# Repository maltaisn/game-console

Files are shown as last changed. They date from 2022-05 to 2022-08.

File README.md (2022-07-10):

# Handheld game console

A small six-button handheld game console with a bootloader and games stored in external flash memory.
A complete solution was created to create, simulate, compile and upload apps for the device.

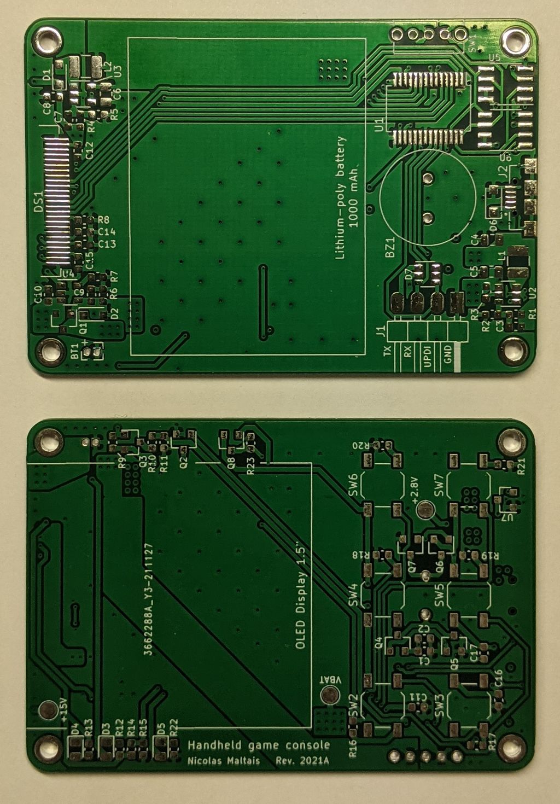
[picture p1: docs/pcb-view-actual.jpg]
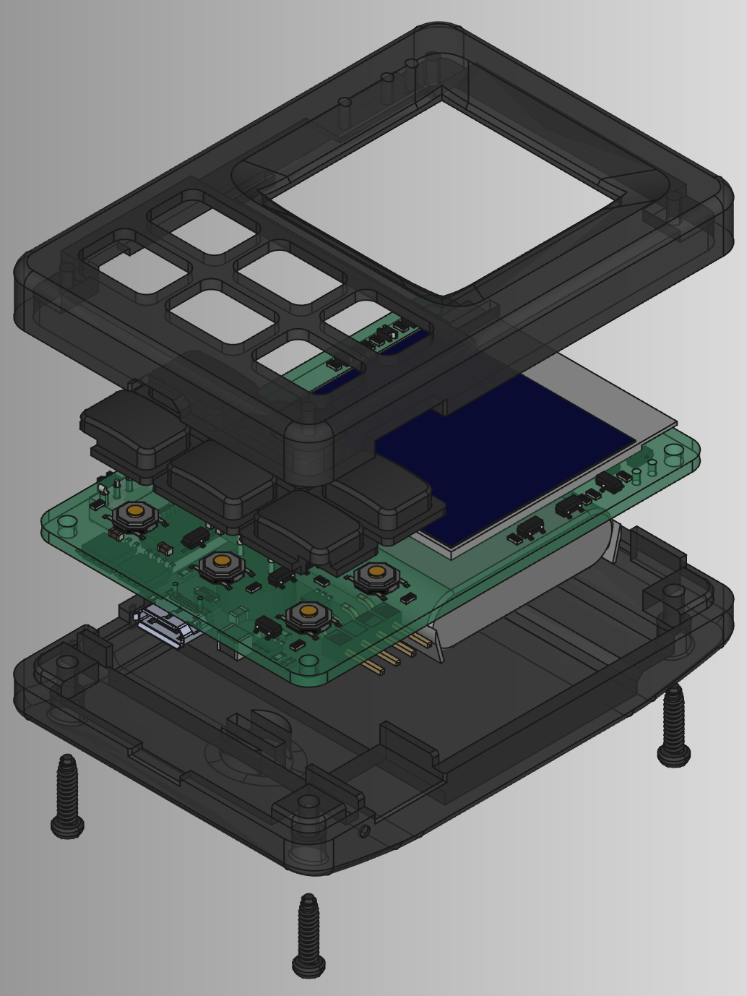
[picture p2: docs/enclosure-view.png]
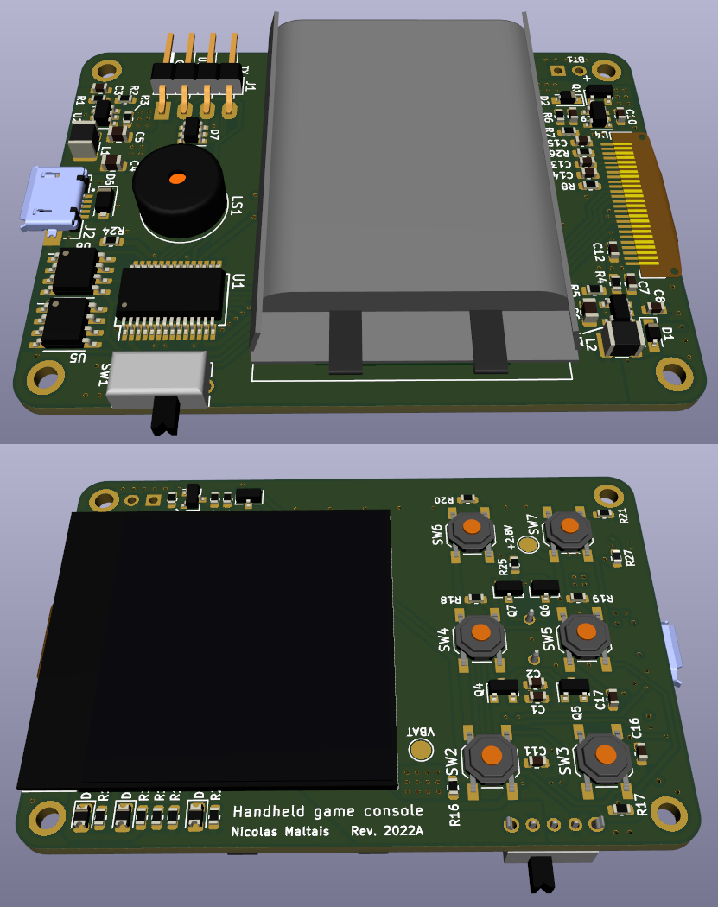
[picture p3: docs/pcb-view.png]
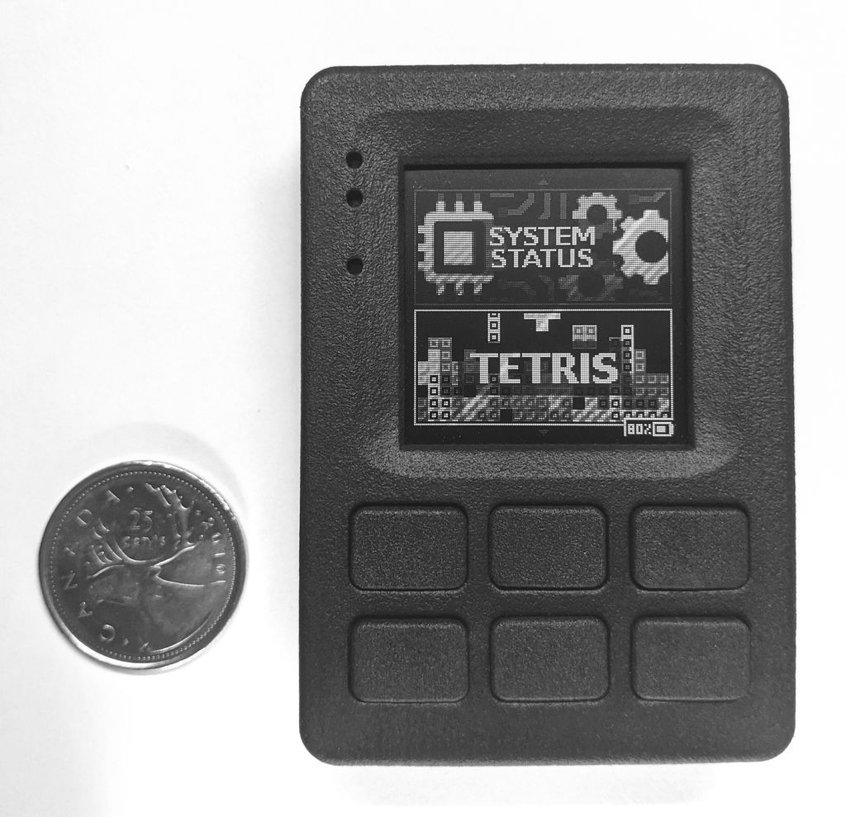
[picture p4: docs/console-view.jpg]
   

There are currently 2 games written for the console:

- [Tetris](sw/app/tetris)
- [Tile World](sw/app/tworld)

## Specifications

- Display: 1.5" OLED 128x128, 4-bit gray.
- MCU: ATmega3208 @ 10 MHz, 4 kB RAM, 32 kB ROM (bootloader uses 8.25 kB).
- Memory: 4 kB EEPROM (up to 64 kB), 1 MB flash (up to 8 MB).
- Physical: 40 mm x 71 mm x 15.4 mm, 60 g.
- Battery: 850 mAh Li-Po, 5-20h active, several months standby, USB micro B charging.

### Hardware

- MCU: ATmega3208, compatible with ATmega4808, AVR128DA28, AVR64DA28, AVR32DA28 (none tested).
- EEPROM: FT25C32A, 4 kB (compatible with same series devices)
- Flash: AT25SF081B, 1 MB (compatible with 25-series flash devices)
- Display: EastRising ER-OLED015-3 (SSD1327 display controller, 15V VCC)

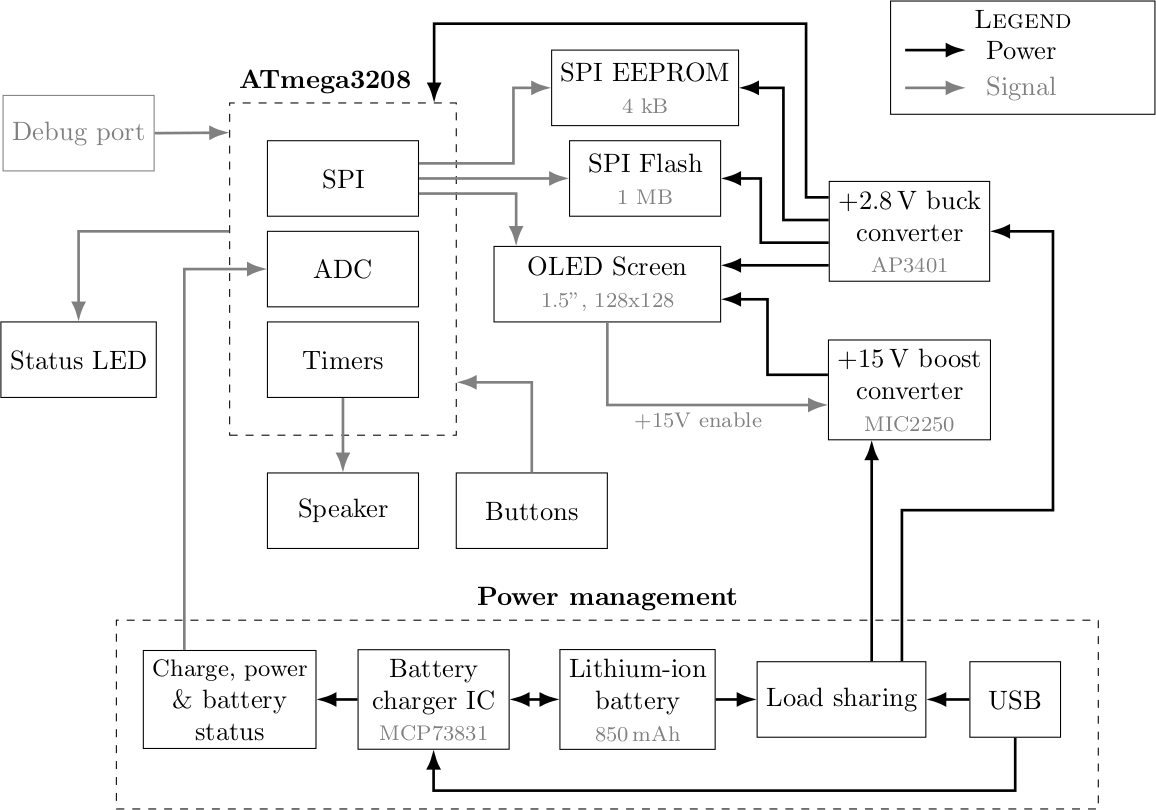
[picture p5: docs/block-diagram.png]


## Tools and building

Everything was built and tested on Linux only (Ubuntu 20.04).
The PCB was made in KiCAD 6 and the enclosure was made in FreeCAD 0.19.
Building and using the software requires the following tools and libraries:

- AVR GCC >= 5.4.0 (7.3.0 used)
- GCC >= 9
- Python >= 3.7
- freeglut, pulseaudio, libpng

## Architecture

The architecture of the software is described in details in [`sw/README.md`](sw/README.md).

## Project structure

- `hw`: PCB and enclosure
- `sw`: all software SDK including programming utility and all apps.
- `docs`: documentation source files

## License

All code is licensed under Apache License 2.0 and all assets are licensed under
Creative Commons v4.0, unless otherwise indicated.
Bitmap fonts were taken from the [u8g2](https://github.com/olikraus/u8g2/wiki/fntlistall) 
project and are not my work. Credits to my brother for making the game music.

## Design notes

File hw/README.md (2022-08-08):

# Game console hardware

## PCB

 

The PCB was designed in KiCAD 6.
Two revisions were made, but only the first revision was manufactured
since it was already working with minor changes.

### Revisions

#### Revision 2021A

- Initial revision.

#### Revision 2022A

- Added pull downs on the H-bridge.
- Removed power monitor (was originally meant to monitor shut off and alert the MCU to do last 
    minute operations, but there isn't anywhere near enough on-board capacity to have time to do so).
- Removed low power reset monitor on the MCU, it caused reset when disconnecting
  the USB cable due to momentary drop on 2.8V power rail (not properly decoupled, battery has protection anyway).
- Changed the battery connector which was too small.

Other notable changes that should be made:

- Battery discharge current reading at ADC to allow better SoC estimation.
- Attempt to reduce high pitch noise (related to either display or 15V boost, 
    may be due to ceramic caps oscillating).
- Increase clearance around buttons for better mechanical integration, or change buttons altogether.
- Remove unused H-bridge to drive speaker (only one side used). Replace bridge pull-downs with pull-ups.
- Replace the debug port with an integrated USB to UART chip.

## Enclosure



The enclosure was designed in FreeCAD and 3D printed in black MJF Nylon.
The design is fine considering this was my first experience with 3D modeling
and considering that it wasn't planned for carefully at the time of designing the
PCB. The button design could have been better, they sometimes get stuck and
don't click, but this is usually not an issue.

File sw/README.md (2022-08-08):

# Game console software

The game console uses an ATmega3208 MCU with 32 kB of ROM and 4 kB of RAM.
The code could easily be ported to MCUs of the same familiy (ATmega4808, AVRxxDA28).
All the code running on the console is written in C, with C++ used only for testing
and Python for utilities.

## Building

Everything is built using Makefiles. The main Makefile includes other files depending on the
build command (simulation, test). A different Makefile is used for AVR, simulation, and testing.
In this text, a *target* refers to either an app or the bootloader, is not to be confused 
with a *Make* target.

Start by making a copy of the `toolchain.template.mk` file and rename it to `toolchain.mk`.
This file will be included from the main Makefile and is used to specify toolchain directory
(avr-gcc and ATmega DFP).

Every target can be built using a variation of the following command:

```shell
make all TARGET=<target-dir> [SIM=<0-1>] [TEST=<0-1>]
```

For exemple:

```shell
make all TARGET=boot  # bootloader, AVR
make all TARGET=boot SIM=1  # bootloader, simulator
make all TARGET=app/system  # system app, AVR
```

Running tests with `TEST=1` is described in a subsequent section.
The bootloader must be built before any app to correctly link with the bootloader functions.
Other noteworthy Make targets include:

- `assets`: only generate assets file, using packing script.
- `compile`: only generate binary file (compile & link).
- `disasm`: output AVR disassembly in build directory.
- `size`: output size information on the AVR binary.

Building creates a `build/` directory in the target's directory, with separate subdirectories
for AVR (`SIM=0` or unset) and the simulator (`SIM=1`).
Note that when switching targets, it may be best to do a full clean, especially
when building the bootloader, since some build related issues have been known to occur.

## Simulation

A GLUT-based graphical simulator is provided to test the bootloader and the apps.
The simulation can be built using the `SIM=1` parameter as explained above.
Nearly all subsystems are simulated: display, input, sound, LEDs, sleep, time keeping,
power management, etc. SPI protocols for the flash and EEPROM are emulated, but not for the display.
UART communication can be done with another application through a socket.
It's notably possible to program the memories with gcprog in simulation.

Simulation reduces considerably the time spent debugging on the actual hardware.
More debugging tools are available in simulation: the GCC sanitizer, `-O0` has little impact on
performance, all symbols are present during debugging, screenshots can be taken of the display, etc.
Moreover, the project doesn't depend on Microchip proprietary debugging tools
and the simulator has helped tremendously with debugging in this regard.

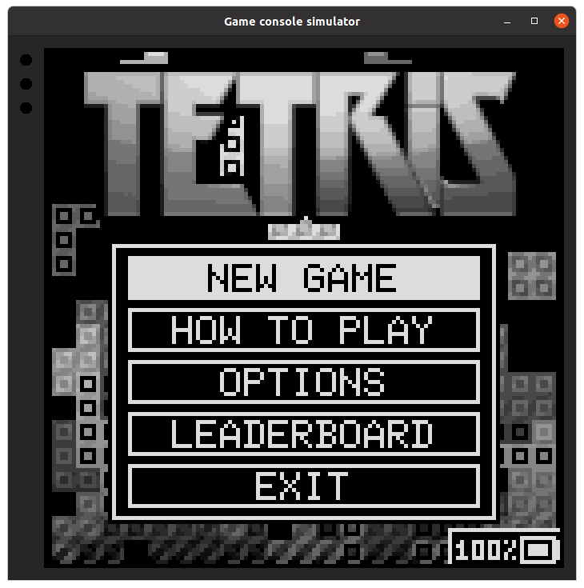
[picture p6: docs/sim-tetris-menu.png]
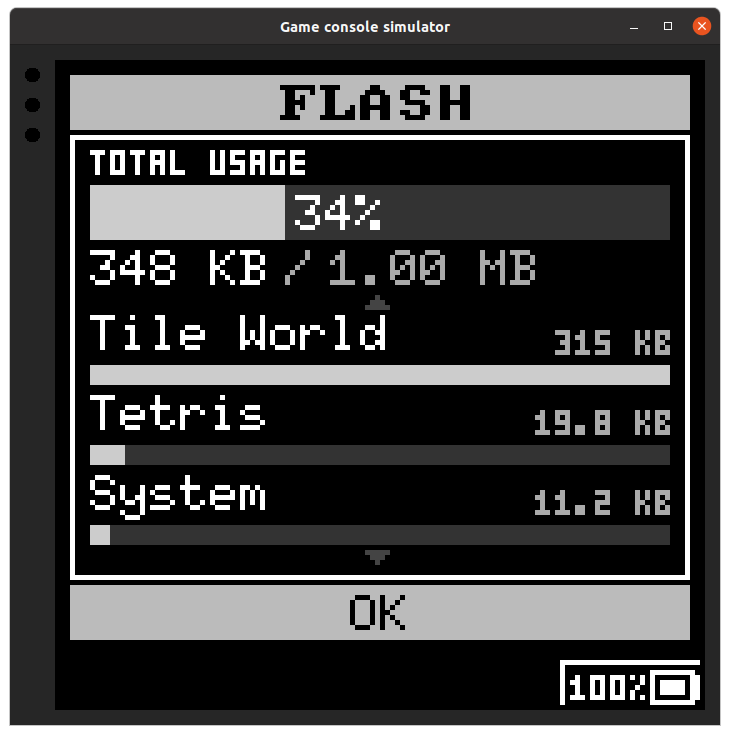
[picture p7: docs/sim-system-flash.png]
 

Notable simulation pitfalls:

- `uint24_t` is defined as a `uint32_t` which may hide some bugs.
- `SHARED_DISP_BUF` has no effect and memory is allocated separatedly.
- Some code is written for a little-endian machine and will not work otherwise.

## Programming

The MCU is programmed via the UPDI protocol, using [pymcuprog](https://pypi.org/project/pymcuprog/).
The SerialUPDI feature is used, the connection is illustrated in the link given. 
During development, a serial adapter with two interfaces has been used, 
one interface connected to the UPDI and the other connected to the game console UART.
All programming is done via a dedicated port with the following pins: TX, RX, UPDI, GND.
The micro USB port is only used for charging.

The bootloader doesn't allow installing apps directly. The communication protocol is instead
implemented in an app, the system app, to reduce the bootloader code size.
When first programming the device or when making changes to the bootloader, this poses a problem
since either the system app is not installed, or it is wrongly linked with the new bootloader.
To counteract this issue, a special Make target is provided to combine both the bootloader and
an app in a single HEX file and flash both at once.
Upon detecting that there are no installed apps or none are compatible with the new bootloader 
version, the bootloader immediately jumps to the app setup without loading the app first.
This Make target is used as follows:

```shell
make preload TARGET=boot PRELOAD=app/system
```
This compiles the bootloader, the system app, and upload the code to the device.
The bootloader can also be flashed by itself with:
```shell
make upload TARGET=boot
```

When developing apps and not changing the bootloader, UPDI isn't used.
The UART interface, the system app, and gcprog are used instead to install, uninstall or modify apps.
Some commands include:
```shell
utils/gcprog.py list  # show details about installed apps
utils/gcprog.py install <app-image>  # to install or update
utils/gcprog.py uninstall <app-id>  # to uninstall
utils/gcprog.py data <app-id> -w <input-file>  # to write EEPROM data
utils/gcprog.py data <app-id> -r <output-file>  # to read EEPROM data
utils/gcprog.py data <app-id> -e  # to erase EEPROM data
```
Before installing an app for the first time, the flash and EEPROM must be initialized
(initialize the index and write the signature):
```shell
utils/gcprog.py init
```
Note that communication will fail if device is sleeping or the system app is not loaded.
All communication is done at a 250K baud rate.
If any operation fails, it should be retried to avoid leaving the device in an invalid state.

App images have a `.app` extension and are generated automatically when building an app using
the app HEX file and the assets generated by the assets packer to be stored in flash.
This is done by the `utils/app_packer.py` script.

## Battery calibration

Battery calibration is performed by first taking measurements with `utils/gcprog.py battery --calib`,
then analyzing the measured data with `utils/battery_calib.py` and writing the resulting file to the
internal EEPROM with pymcuprog.

The battery percentage estimation process is very approximate even with the calibration.
Since the hardware has no battery monitor, current monitor, or any specialized hardware to track
the SoC other than the battery voltage, everything must be derived from the latter.
One key problem is that battery voltage varies with load, and the current is unknown.
As such, the load is estimated using the average screen color and contrast since these are the
main load parameters, with the display accounting for over 90% of the current consumption (figure 2).
Points are taken from the discharge voltage curve and simple interpolation can give an approximate
battery level (figure 3).
Overall this works very badly, but it's better than nothing!

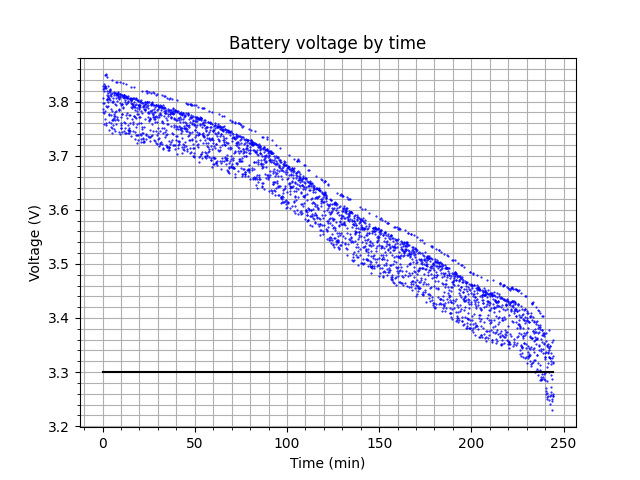
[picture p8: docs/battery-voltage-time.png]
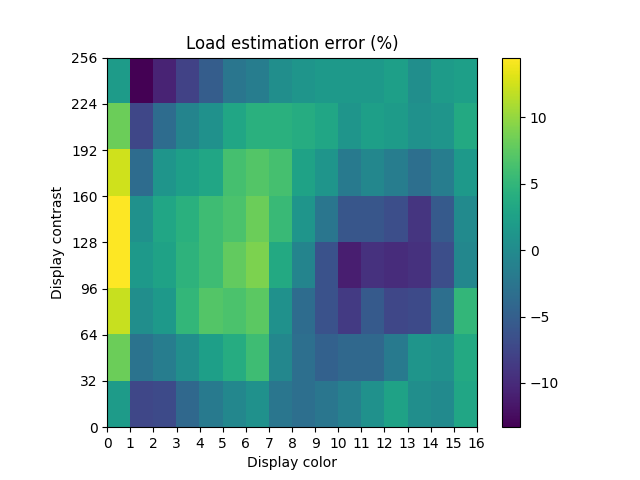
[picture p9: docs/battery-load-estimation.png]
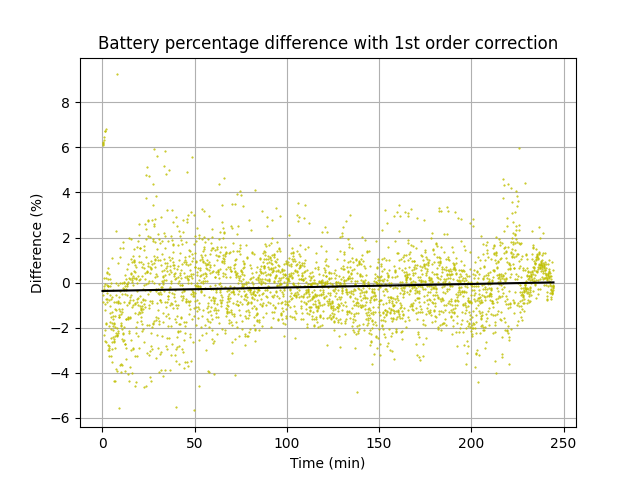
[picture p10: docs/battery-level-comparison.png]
  

## Architecture

The game console architecture is centered around the fact that resources are limited.
As such, core functions are optimized for performance and size, and all RAM usage is accounted for.
Optimization and achieving a lot with little were core goals of this project, so many architecture
decisions made tend to complicate things and would not be relevant to other projects.

Although nearly all the code is written in C and only a little Assembly, the disassembly has 
often been inspected during development to ensure proper performance and small code size.

This may explain some oddities, for example: 
- Use of gotos, unions, absence of switch statements.
- `uint24_t` data type used profusely to save one byte.
- Abundant use of bitwise arithmetic.
- Strict use of volatile.
- Uninitialized local variables.
- Seemingly unneeded shifts to infer nibble swap instruction. 
- General lack of protection and validation (compensated by using the simulator).

### Bootloader and app

The compiled code is split into two parts: the "bootloader" and the "app".
A list of callbacks is defined to serve as a kind of interrupt vector.
The bootloader is linked against symbols with the predefined addresses of the callback vector table,
as defined in `boot/callbacks.sym`.
Despite its name, the bootloader keeps control of the program execution at all times, even after
an app has been started. The main loop is located in the bootloader and handles low level tasks
like filling sound track buffers and power management.
Callbacks are called to give control to the app, for updating, drawing, power management 
events, etc. Some MCU interrupts are forwarded to a callback.
The bootloader currently has support for up to 32 different apps, but this is easily changed.

The bootloader also has several functions marked as noinline to allow them to be called from the
app and save on code size. This is a bit unwiedly but there seemed to be no alternative short of
writing a script to identify these functions and mark them automatically (if that's even possible). 
Symbols for statically allocated variables and for the noinline functions are
output to the `boot/build/boot.sym` file during build to allow the app to link against them.
These symbols are not defined at all when compiling the app to force the linker to use the existing
symbols. Some symbols are prefixed with an underscore `_` to avoid ending up in that file.

To load an app, the bootloader copies its code from the external flash memory to the section in
internal program memory reserved for that purpose. This is not ideal as the internal memory has
a limited number of write cycles (10000), but this issue is not significant.
The MCU costs 1$ in any case, so I'll replace it if it ever fails.
When copying program data, the CRC is checked to ensure correctness.
The bootloader then initializes offsets within the flash and EEPROM for relative reads and
jumps to the setup callback to allow the app to initialize itself.

### Flash & EEPROM index

The memory layout for the external flash and EEPROM is described in `include/sys/flash.h` and
`include/sys/eeprom.h` respectively. In both cases, an index is present to indicate how much space
each app has allocated in it. The flash index also has more info (version, name, CRC, etc).
The indices are updated by the gcprog script when installing and uninstalling apps.

### Memory layout & linking

There is a linker script for the bootloader and one for the app.
Note that numbers given here are for the ATmega3208 and may change if ported to another device.

The bootloader occupies the first 8.25 kB of the program memory, leaving 23.75 kB for the app.
As for RAM, since both parts (bootloader & app) run at the same time, some sections are shared and used by both.
The app has access to 3 936 bytes of RAM to store its data, the display buffer and the stack.

Some variables may be placed alongside the display buffer to be used as temporary storage when
the display buffer isn't used. The boot-only is for variables used only before loading an app.
The display buffer may have a different size in the bootloader and the app.
Sufficient space must be left for the stack when designing an app.
The memory layout is illustrated in the figure below. Gray sections are uninitialized.
BSS sections are zero initialized.

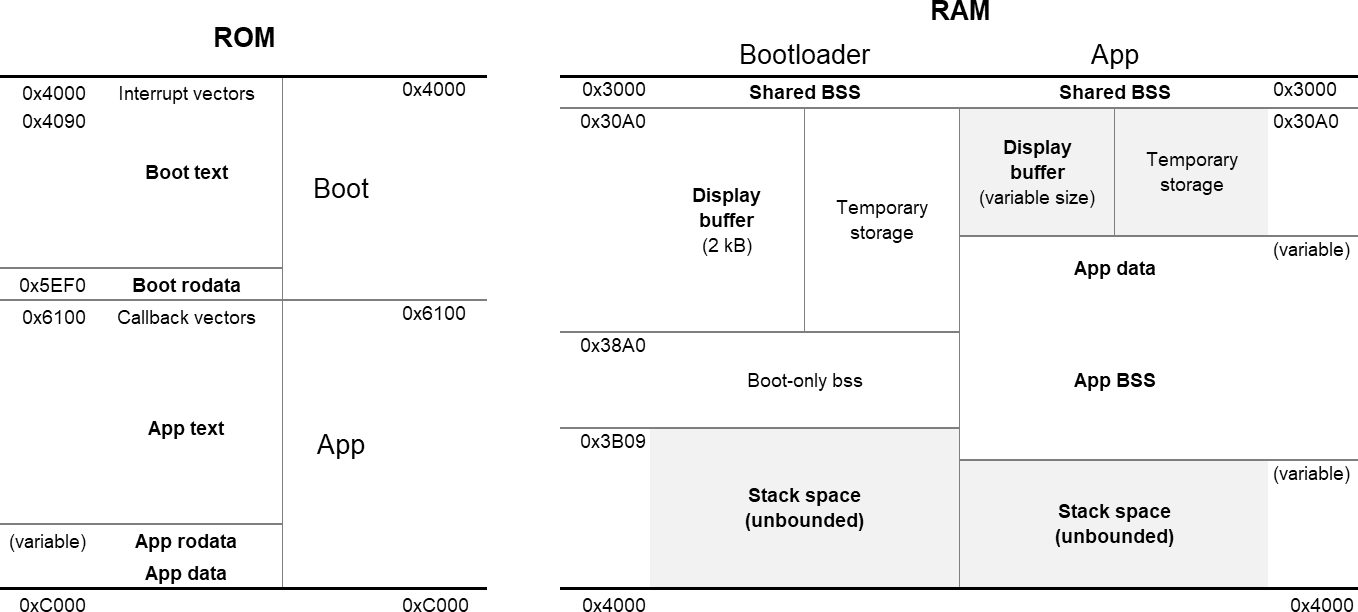
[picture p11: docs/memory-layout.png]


A custom script to report the bootloader and app size is located in `utils/`
to replace the traditional `avr-size` which doesn't work with custom linker scripts.

### Project structure

#### Core library

The core library is the "safe" API meant to be used from an app.
The implementation of this library is in the `core/` directory and is the same for AVR and 
the simulator. The header files are located in `include/core/`.

Several functions are only a thin wrapper around a system library function.
Note that there are a few `sys_` prefixed functions implemented in the core library,
to allow using the same implementation for the simulator, without making part of the core API.

#### System library

The system library implements all the low level logic and can be seen as a kind of high level HAL.
The system library API is accessible from the app but not necessarily safe to use.
It handles power management, GPIOs, external memory and display interfacing, etc.
This library has two implementations, one in `sys` for AVR, and one in `sim` for the simulator.
The header files are located in `include/sys/`.
The simulator also implements extra functionality for debugging available through the
header files in `include/sim`.

Note that the system library exposes several global variables.
Unless under specified, these are never meant to be used directly, they are declared as extern
(and not static) for linking purposes.

#### Boot library

This library is an extension of the system library used only by the bootloader.
It is not linked with the app, therefore it's not accessible from it.
There is also two implementations of this library, for AVR and the simulator.
The header files are located in `boot/include/boot/` and the implementation is located
alongside the system library implementation in `sys/` and `sim/`.

#### Bootloader

The bootloader is located in the `boot/` directory.
See the [Bootloader and app](#bootloader-and-app) section for description of the bootloader.

#### Apps

Apps are all located in a subfolder of the `app/` directory.
Each app must follow the same file and directory structure:

- `assets/`: assets files.
- `include/`: header files.
- `src/`: implementation files.
- `test/`: test source files (if any).
- `target.cfg`: configuration file.
- `target.mk`: Makefile included during build.
- `pack.py`: script used to pack assets.

The `target.cfg` file contain the following fields:
- `id`: app ID, must be unique (required).
- `version`: app version (required).
- `title`: app name/title (required).
- `author`: author name (required).
- `display_page_height`: initial display page height set when loading the app (required).
- `eeprom_space`: size in bytes reserved in EEPROM (optional, default 0).

The assets packing script is run when using the `all` or `assets` Make targets.
The script generates a header file in `include/assets.h`, a data file with packed assets 
`assets.dat` and in some cases another data file `src/assets.c` for assets stored internally.

#### Test

The project contains very little tests.
The only tests present for the core functionality are those for the graphics module.
They were mostly used for regression testing after making optimizations.

Tests for a particular target (including the `test` target) can be run with the following command:
```shell
make test TARGET=<target-dir> TEST=1
```

The tests run in headless simulator mode, meaning the simulator has no `main`, no GUI, 
produce no sound, but other simulated system functions are still available and time is controllable.

#### Utilities

All utilities are written in Python and contained in the `utils/` directory.
Requirements can be install with:
```shell
pip3 install -r requirements.txt
```

- `avr_size.py`: replacement for `avr-size`, mentionned above.
- `boot_sym_filter.py`: used to generate the `build/boot/boot.sym` file.
- `assets_packer.py`: used from `pack.py` scripts to encode assets and 
    pack them to a single binary file.
- `app_packer.py`: packages app code and data into a single binary file used by gcprog.
- `gcprog.py`: short for Game Console Programmer, used to manage apps on the device.
    This utility can also be run in "local" mode to generate flash and eeprom images 
    for the simulator.
- `battery_calib.py`: used to analyzed measured battery data to generate calibration data.

Utilities for encoding assets are also usable as standalone applications:

- `assets/image_gen.py`: various image formats -> encoded image
- `assets/sound_gen.py`: MIDI sound file -> encoded sound tracks
- `assets/font_gen.py`: 1-bit image with font glyphs -> encoded bitmap font

### Defines

There are several special defines that are set during compilation:

- `BOOTLOADER`: the bootloader is present in the build (always true during simulation).
- `SIMULATION`: the simulation is being built.
- `SIMULATION_HEADLESS`: the simulation is being built without the main function.
- `SIM_MEMORY_ABSOLUTE`: external memories are used in absolute mode (i.e. the whole memory is loaded).
- `TESTING`: tests are being built.
- `RUNTIME_CHECKS`: enables runtime checks in several locations (usually for simulation).

## Resource usage

The following peripherals and interrupts are used in the microcontroller:

- All GPIOs except PA7.
- `GPIO`: all 4 general purpose I/O registers (`PORTD_PORT`).
- `BOD` (set by fuse at 1.8V)
- `RTC`: time keeping (system tick), power monitoring, sound updates (`RTC_CNT`).
- `PIT`: power monitoring (`RTC_PIT`).
- `ADC0`: used for reading battery level (`ADC0_RESRDY`).
- `USART0`: used for communication in system app (`USART0_DRE`, `USTART0_RXC`).
- `SPI0`: used to communicate with display and external memory.
- `TCA0`: split mode, all 3 HCMP channels used for generating sound PWM.
- `TCB0`: sound channel 0 (`TCB0_INT`).
- `TCB1`: sound channel 1 (`TCB1_INT`).
- `TCB2`: sound channel 2 (`TCB2_INT`).

## Modules

The core, system and boot libraries are separated into similarly named modules
encompassing similar functionality. Notable modules are:

- **data**: provides an unified memory map to load data from the external flash or
    the internal program memory. Used to load all built-in asset types.

- **dialog**: provides basic dialog UI to have an unified looks across apps.

- **display**: functions related directly to the display (contrast, display buffer, etc).
    Note that the display is updated in a paged way 
    ([explained here](https://github.com/olikraus/u8glib/wiki/tpictureloop)),
    to use less RAM, since there's not enough RAM to contain the whole display buffer.
    The page height is variable at runtime.

- **eeprom**: external EEPROM reading and writing (atomically).

- **flash**: external Flash reading.

- **graphics**: graphics primitives (lines, rectangles, text, images), built upon the display module.
    The image format and the font format are described in `core/graphics.h`.

- **init**: low-level initialization of registers, initialization of other modules.

- **input**: handles user input (buttons) and inactivity sleep.

- **led**: handles the status LED.

- **power**: handles power monitoring and management, sleep and sleep scheduling, 
    battery level estimation.

- **sound**: handles sound tracks, decoding sound data, driving the speaker.
    The sound format is described in `core/sound.h`.

- **time**: keeps track of system time, in ticks (1/256th of a second).
    Also takes care of periodic updates for other modules (sound, led, input).

- **uart**: available by defining `SYS_UART_ENABLE`, provides UART communication functionality.

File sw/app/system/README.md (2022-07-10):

# System app

The system app is used to view system status: installed apps, flash & EEPROM usage,
battery level and status.
The app also implements the communication protocol to program the Flash and EEPROM
from `gcprog.py`.

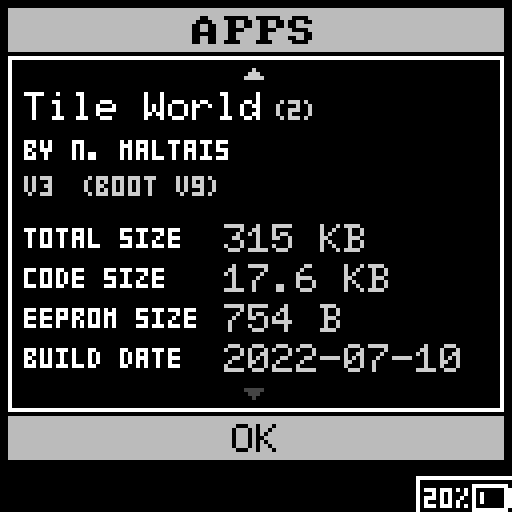
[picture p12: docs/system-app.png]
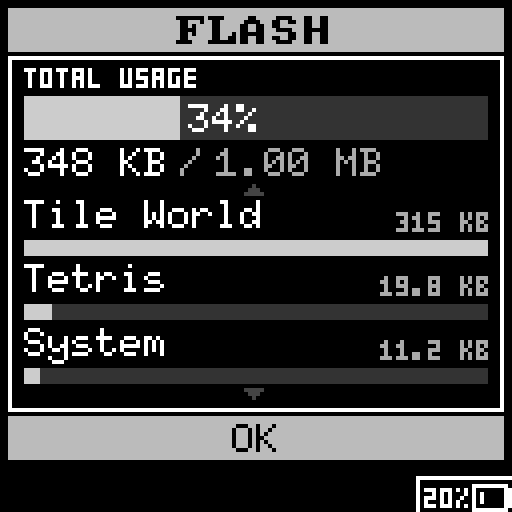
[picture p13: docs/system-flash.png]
 
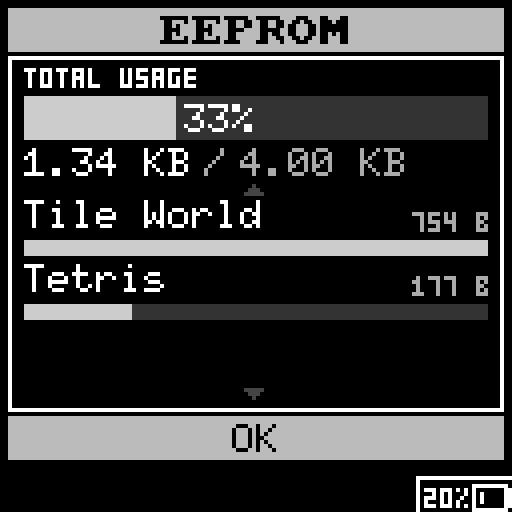
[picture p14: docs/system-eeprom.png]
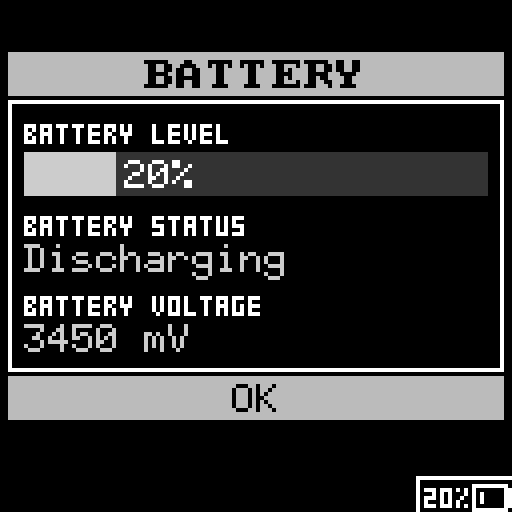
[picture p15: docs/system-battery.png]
 

The simulator emulates the UART communication with sockets.
Since the Flash and EEPROM SPI interfaces are also emulated, `gcprog.py` can be fully
tested in the simulator. This is done using the `--sim` flag.

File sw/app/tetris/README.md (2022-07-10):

# Tetris

Simple Tetris implementation, with rules as specified by the 
[Tetris Guideline](https://tetris.wiki/Tetris_Guideline).

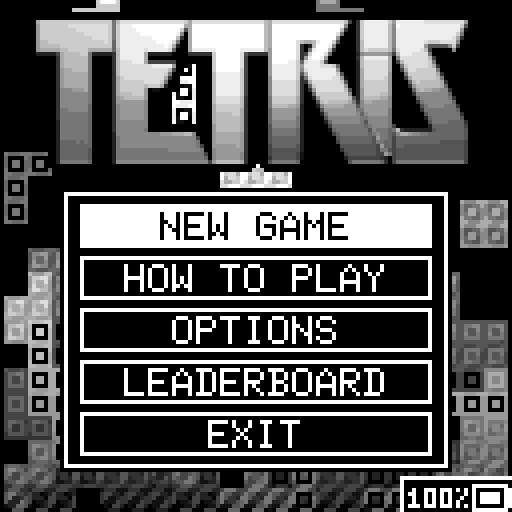
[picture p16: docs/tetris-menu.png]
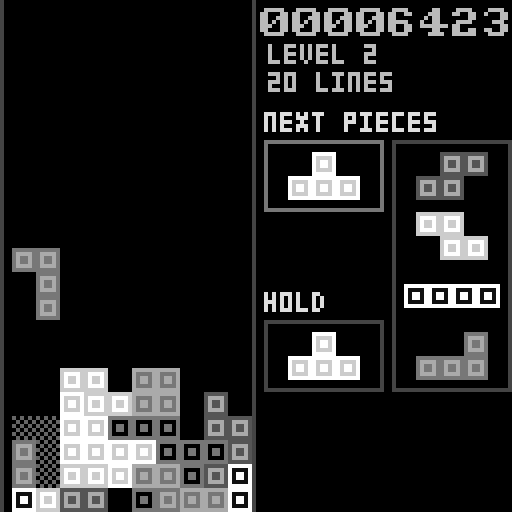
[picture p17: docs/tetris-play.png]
 
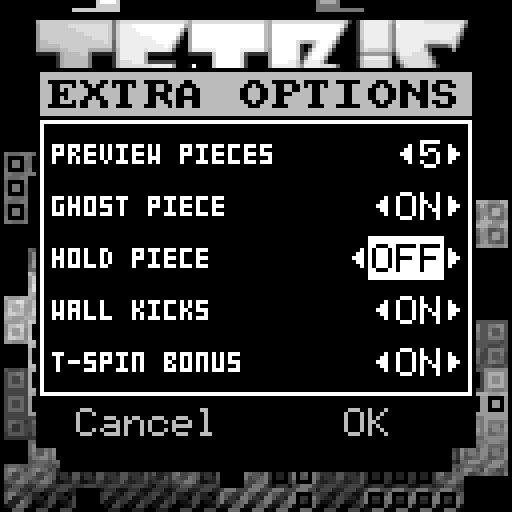
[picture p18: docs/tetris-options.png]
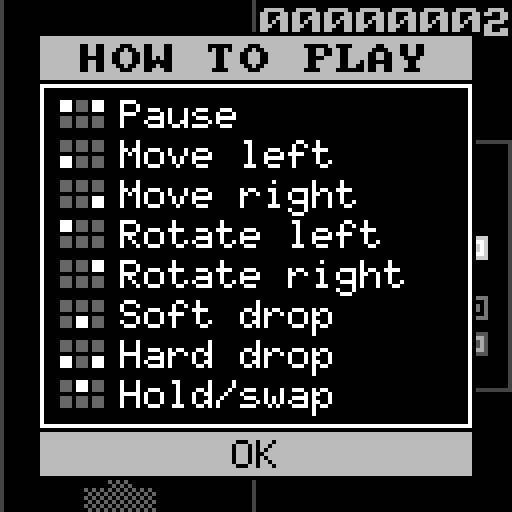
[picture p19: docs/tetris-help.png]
 

**Features:**

- 10x22 game grid.
- Up to 5 pieces preview (configurable).
- Ghost piece (can be disabled).
- Hold piece (can be disabled).
- Wall kicks to move blocked piece on rotation.
- T-Spin, perfect clear, combo and back-to-back scoring rules.

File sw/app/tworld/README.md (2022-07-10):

# Tile World

This game is an implementation of [Chip's Challenge](https://wiki.bitbusters.club/Chip%27s_Challenge),
originally released on the Atari Lynx but more commonly known for the version shipped with early 
Windows versions.
The game is more specifically a very close copy of [Tile World](https://wiki.bitbusters.club/Tile_World) (v1.4.0).
The original source code is available [here](https://github.com/Qalthos/Tile-World).

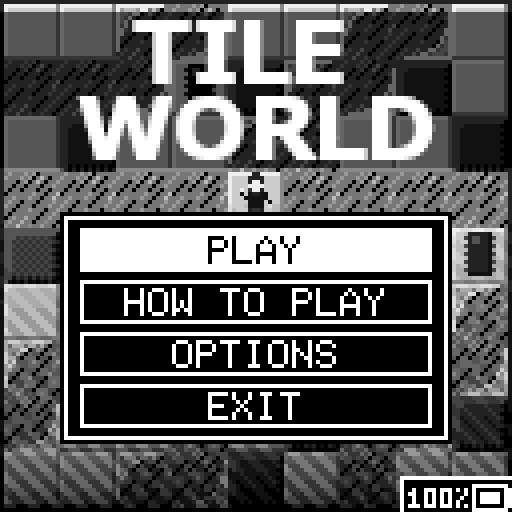
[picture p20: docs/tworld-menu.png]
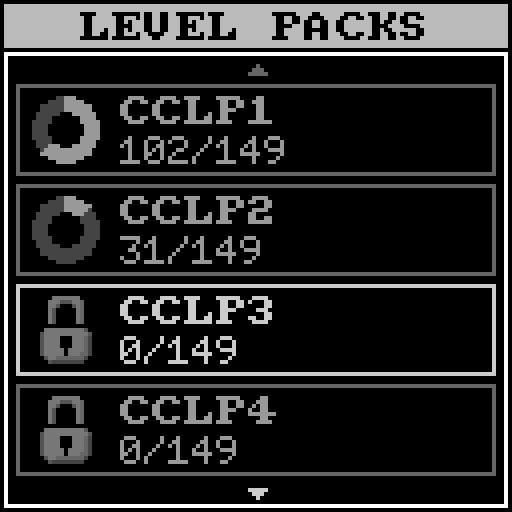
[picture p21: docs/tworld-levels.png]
 
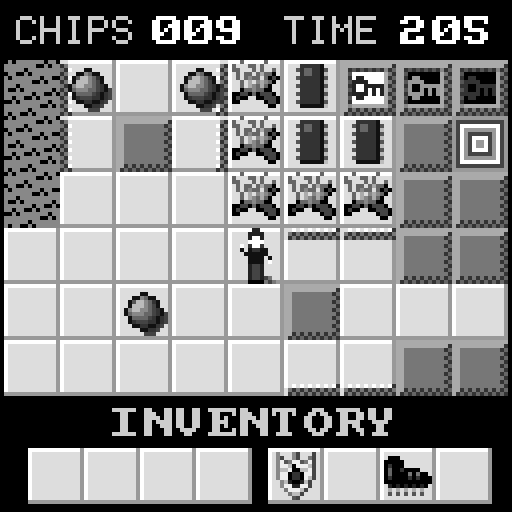
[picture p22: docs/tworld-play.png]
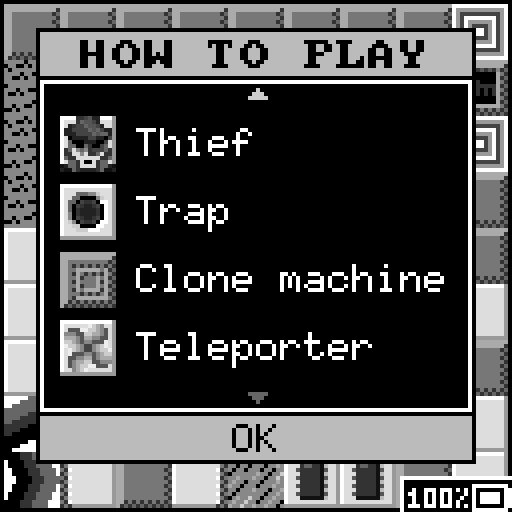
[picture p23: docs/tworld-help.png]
 

**Features:**

- Fully compatible with the Lynx ruleset.
- Level pack selection and level selection.
- Using a password to go a level.
- Best level time is saved upon completion.
- Help dialog for tile types (helps with knowing which key is blue and which button is red on a grayscale display!)

The implementation is very similar to Tile World's, with a few changes to reduce the memory usage:

- Actor list is limited to 128 actors.
- Static actors and ghost blocks are introduced to avoid this limit.
- `cr->tdir` and `cr->fdir` are not used, only `cr->dir`.
- No per creature flags (slide token, reverse, pushed, teleported).
    These are replaced by a state value and should be 100% equivalent.
- Only actor position, stepping and state are stored in actor list,
    the rest is taken from the grid (entity, direction).
- Instead of "move laws" array, the tile IDs were remapped carefully to reduce
    the amount of logic needed to determine whether the tile is a wall.
    The ID remap is shown below.

### Resource usage

#### Memory 

- Display buffer: 1408 B (6 pages of 22 px).
- Level grid: 1536 B.
- Actor list: 256 B.
- Other level state: 30 B.
- Dialog module: 62 B.
- Misc. game state: 42 B.
- **Total**: 3334 B (+ stack space).

#### CPU

Drawing routines for tiles are optimized so that the game can be run at best at 
16 FPS (i.e. one game step per display refresh), and usually in the 12-15 FPS range.
Refresh rate will be lower if many actors are on screen or if level has many active actors
but should not normally go under 8 FPS during gameplay.

### Tile IDs

The game grid is made of two layers: the top layer and the bottom layer.
The bottom layer is always static and the top layer contains only actors.
Tiles on both grids are encoded on 6 bits, as follows:

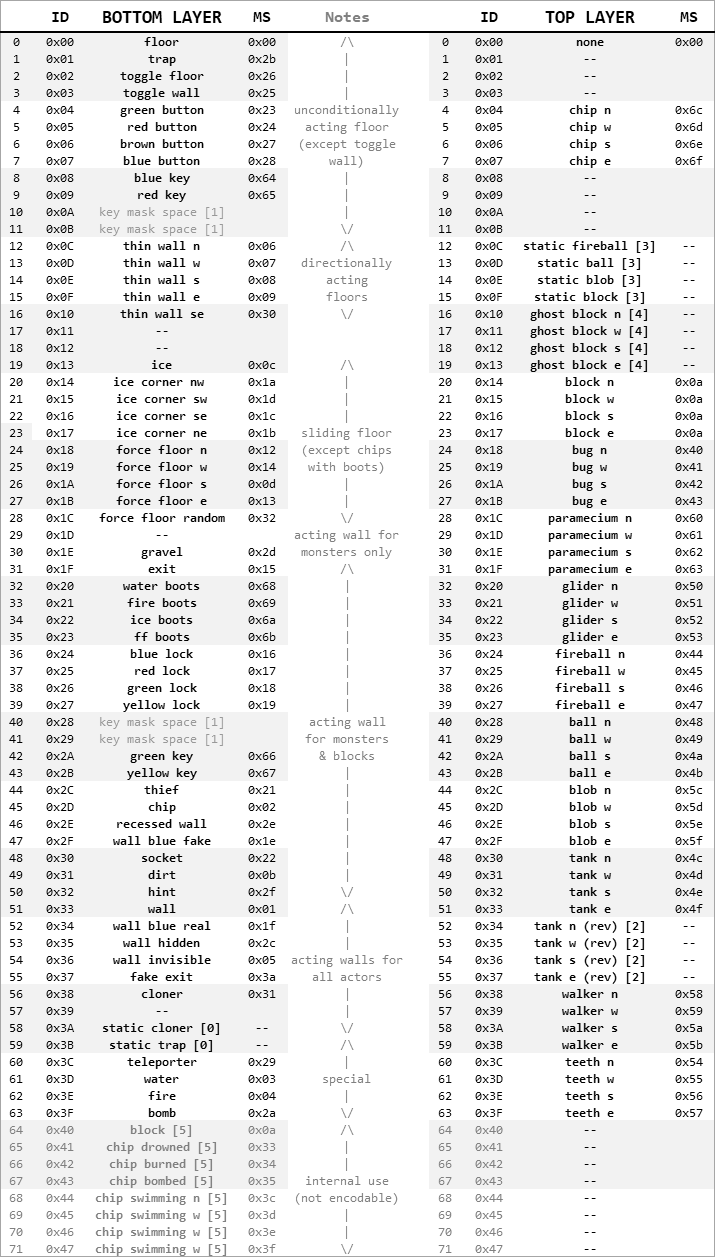
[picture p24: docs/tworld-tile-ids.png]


**Notes**

**[0]**: Static tiles are like their counterpart but actors placed on them are static (i.e. not added to the actor list). \
**[1]**: These IDs match the `is_key` macro. Keys were split since the blue and red keys act as floor unlike the yellow and green keys. \
**[2]**: Tanks have a "reversed" variant to replace the `REVERSED` flag that couldn't added due to memory limitations. \
**[3]**: These tiles appear non-directional so a static variant exist that isn't added to the actor list (but can still kill). \
**[4]**: Ghost blocks are not initially added to the actor list, only when pushed. \
**[5]**: Tiles only used internally for extra bottom tile images, not encodable in level data.

### Level packs

The included level packs are community-created CCLP1, CCLXP2, CCLP3, and CCLP4,
for a total of 596 levels.

Minor changes were made to some levels to accomodate the actor list limit, but they remain solvable,
most of the time with the official TWS (labeled with "no effect"). 
All changes made to the levels are described below.
Note that without these changes and by temporarily disabling the actor limit in the Python
implementation, all tests pass with the original TWS solutions.

Level titles and hints were kept as is, without changing mentions of colors, like "blue key" or
"red button", despite the screen being grayscale. This is slightly annoying but easy to adjust to.

#### [CCLP1](https://wiki.bitbusters.club/CCLP1)

- Level 99: ghost blocks used.
- Level 118: removed rows of fireball & retimed fireball spacing.

#### [CCLXP2](https://wiki.bitbusters.club/Chip%27s_Challenge_Level_Pack_2_(Lynx))

- Levels 71, 98, 127: replaced burned/drowned chip tiles with walls.
- Levels 31, 74: cloners will be emptied, to little effect.
- Level 57: tanks used to disable cloners after some time.
- Level 148: cloners will be emptied, adding a tighter time constraint to the level.

#### [CCLP3](https://wiki.bitbusters.club/CCLP3)

- Level 107: ghost blocks used.

#### [CCLP4](https://wiki.bitbusters.club/CCLP4)

- Levels 38, 44, 77, 83, 95: ghost blocks used.
- Levels 36, 50: replaced unused blocks with walls
- Level 31: ghost blocks used, several ball alleys disabled at start and enabled later (official solution fails, still solvable).
- Level 40: changed timing setup to avoid cloners emptying (official solution fails, still solvable).
- Level 65: ghost blocks used, official solution fails. Still solvable, but skipped during testing.
- Level 67: cloners get emptied, to little effect.
- Level 71: original solution fails due to static blocks changing initial swap with chip, still solvable.
- Level 125: slightly moved blob colliding with chip due to one static blob changing PRNG state evolution.

### Testing

To test the game, one test per level is made, using the official solution recorded in a TWS file.
These files are located in `test/tws`. To run the tests, run the following command:
```shell
make test TARGET=app/tworld TEST=1
```

### Level conversion

Levels are converted from the MS DAT format to a more compact format with re-encoded tile IDs.
The conversion is done in several steps:

1. Read the MS DAT file.
2. Re-encode tile IDs.
3. Layer preprocessing steps: 
    - Replace unlinked traps and cloners with their static counterpart.
    - Replace unmoveable blocks with static blocks.
    - Replace stuck non-directional monsters with their static version.
    - Replace initially unmoving blocks with no side effects with ghost blocks (if enabled for level).
4. Compress layer data with LZSS. 
     This results in a 30-50% better compression that the usual run-length encoding.
5. Write final level data file.

The level converter is integrated with the game console assets packer, but can be run in standalone mode:
```shell
./dat_convert.py <level-pack.dat> [-o <output.dat>]
```

### Python implementation

As a proof of concept, the game was originally written in Python, with pygame.
Tile World uses much more memory than was available and I wasn't sure if the game
could be made in a fully compatible way, so I implemented it separatedly first.
The Python implementation is available from `utils/tworld_gui.py`:

```shell
./tworld_gui.py <level-pack.dat>[:<level-number] [--full-map] [--solution <solutions.tws>]
```

This implementation allows viewing the full map as well as viewing and single-stepping TWS solutions.
Automated level tests are also available in `tworld_test.py`:

```shell
./tworld_test.py <level-pack.dat> <solutions.tws> [--level <level-number]
```

### Credits

All credits for making the level packs goes to the Chip's Challenge community.
The code in `tworld.c` should be considered GPL-2.0 licensed to respect the Tile World license.
Credits to my brother for making the music and the grayscale tileset.

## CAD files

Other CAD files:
hw/enclosure.FCStd

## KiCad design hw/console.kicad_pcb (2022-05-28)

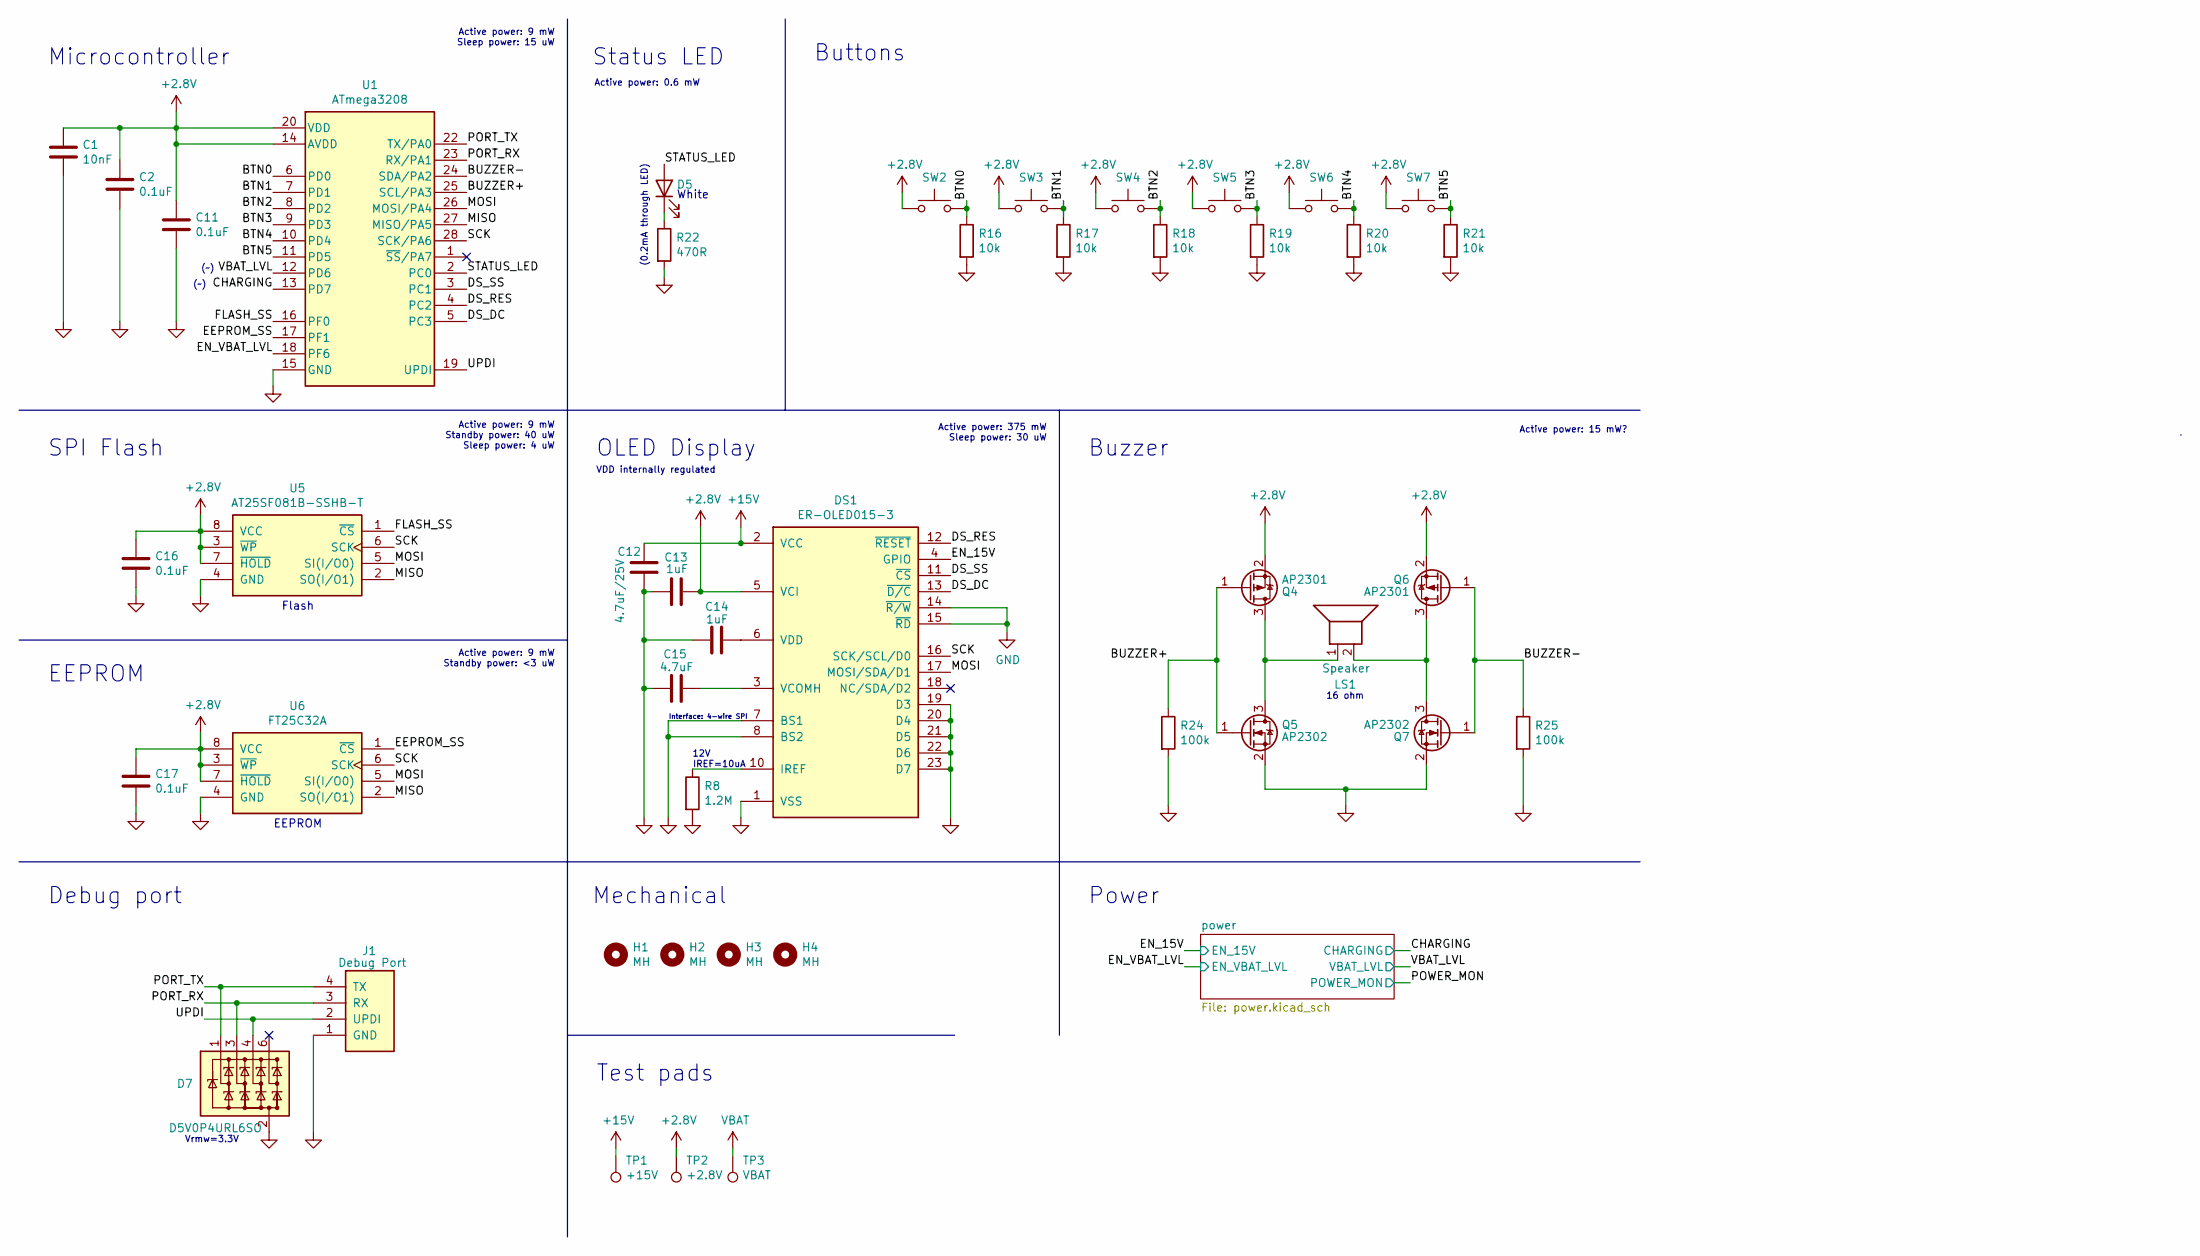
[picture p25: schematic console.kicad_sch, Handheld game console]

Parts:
C1: 10nF; C_0603_1608Metric
C2, C11, C16, C17: 0.1uF; C_0603_1608Metric
C12: 4.7uF/25V; C_0603_1608Metric
C13, C14: 1uF; C_0603_1608Metric
C15: 4.7uF; C_0603_1608Metric
D5: LED; D_0805_2012Metric
D7: D5V0P4URL6SO; SOT-23-6
DS1: ER-OLED015-3
H1, H2, H3, H4: MH; MountingHole_2.2mm_M2_ISO7380_Pad
J1: Debug Port; Debug_Port
LS1: Speaker
Q4, Q6: AP2301; SOT-23
Q5, Q7: AP2302; SOT-23
R8: 1.2M; R_0603_1608Metric
R16, R17, R18, R19, R20, R21: 10k; R_0603_1608Metric
R22: 470R; R_0603_1608Metric
R24, R25: 100k; R_0603_1608Metric
SW2, SW3, SW4, SW5, SW6, SW7: SW_Push; SW_SPST_TL3342
TP1: +15V; TestPoint_Pad_D2.0mm
TP2: +2.8V; TestPoint_Pad_D2.0mm
TP3: VBAT; TestPoint_Pad_D2.0mm
U1: ATmega3208; SSOP-28_5.3x10.2mm_P0.65mm
U5: AT25SF081B-SSHB-T; SOIC-8_3.9x4.9mm_P1.27mm
U6: FT25C32A; SO-8_3.9x4.9mm_P1.27mm

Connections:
+2V8: C1.1, C2.1, C11.1, C13.1, C16.1, C17.1, DS1.5 (VCI), Q4.2 (S), Q6.2 (S), SW2.1, SW3.1, SW4.1, SW5.1, SW6.1, SW7.1, TP2.1, U1.14 (AVDD), U1.20 (VDD), U5.3 (~WP), U5.7 (~HOLD), U5.8 (VCC), U6.3 (~WP), U6.7 (~HOLD), U6.8 (VCC); also elsewhere on the board
+15V: C12.1, DS1.2 (VCC), DS1.24 (VCC), TP1.1; also elsewhere on the board
/BTN0: R16.1, SW2.2, U1.6 (PD0)
/BTN1: R17.1, SW3.2, U1.7 (PD1)
/BTN2: R18.1, SW4.2, U1.8 (PD2)
/BTN3: R19.1, SW5.2, U1.9 (PD3)
/BTN4: R20.1, SW6.2, U1.10 (PD4)
/BTN5: R21.1, SW7.2, U1.11 (PD5)
/BUZZER+: Q4.1 (G), Q5.1 (G), R24.1, U1.25 (SCL/PA3)
/BUZZER-: Q6.1 (G), Q7.1 (G), R25.1, U1.24 (SDA/PA2)
/CHARGING: U1.13 (PD7); also elsewhere on the board
/DS_DC: DS1.13 (~D/C), U1.5 (PC3)
/DS_RES: DS1.12 (~RESET), U1.4 (PC2)
/DS_SS: DS1.11 (~CS), U1.3 (PC1)
/EEPROM_SS: U1.17 (PF1), U6.1 (~CS)
/EN_15V: DS1.4 (GPIO); also elsewhere on the board
/EN_VBAT_LVL: U1.18 (PF6); also elsewhere on the board
/FLASH_SS: U1.16 (PF0), U5.1 (~CS)
/MISO: U1.27 (MISO/PA5), U5.2 (SO(I/O1)), U6.2 (SO(I/O1))
/MOSI: DS1.17 (MOSI/SDA/D1), U1.26 (MOSI/PA4), U5.5 (SI(I/O0)), U6.5 (SI(I/O0))
/PORT_RX: D7.3 (K2), J1.3 (RX), U1.23 (RX/PA1)
/PORT_TX: D7.1 (K1), J1.4 (TX), U1.22 (TX/PA0)
/SCK: DS1.16 (SCK/SCL/D0), U1.28 (SCK/PA6), U5.6 (SCK), U6.6 (SCK)
/STATUS_LED: D5.2 (A), U1.2 (PC0)
/UPDI: D7.4 (K3), J1.2 (UPDI), U1.19 (UPDI)
/VBAT_LVL: U1.12 (PD6); also elsewhere on the board
GND: C1.2, C2.2, C11.2, C12.2, C13.2, C14.1, C15.1, C16.2, C17.2, D7.2 (VSS), DS1.1 (VSS), DS1.7 (BS1), DS1.8 (BS2), DS1.9 (VSS), DS1.14 (~R/W), DS1.15 (~RD), DS1.19 (D3), DS1.20 (D4), DS1.21 (D5), DS1.22 (D6), DS1.23 (D7), DS1.25 (VSS), J1.1 (GND), Q5.2 (S), Q7.2 (S), R8.2, R16.2, R17.2, R18.2, R19.2, R20.2, R21.2, R22.2, R24.2, R25.2, U1.15 (GND), U1.21 (GND), U5.4 (GND), U6.4 (GND); also elsewhere on the board
unnamed: C14.2, DS1.6 (VDD)
unnamed: C15.2, DS1.3 (VCOMH)
unnamed: D5.1 (K), R22.1
unnamed: DS1.10 (IREF), R8.1
unnamed: LS1.1, Q4.3 (D), Q5.3 (D)
unnamed: LS1.2, Q6.3 (D), Q7.3 (D)
VBAT: TP3.1; also elsewhere on the board

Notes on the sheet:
SPI Flash
Microcontroller
Debug port
16 ohm
Buttons
Interface: 4-wire SPI
Test pads
Flash
Power
Vrmw=3.3V
Active power: 375 mW Sleep power: 30 uW
(~)
White
Mechanical
IREF=10uA
EEPROM
OLED Display
Active power: 15 mW?
Active power: 9 mW Standby power: <3 uW
Buzzer
Active power: 9 mW Sleep power: 15 uW
Status LED
12V
VDD internally regulated
Active power: 0.6 mW
Active power: 9 mW Standby power: 40 uW Sleep power: 4 uW
(0.2mA through LED)

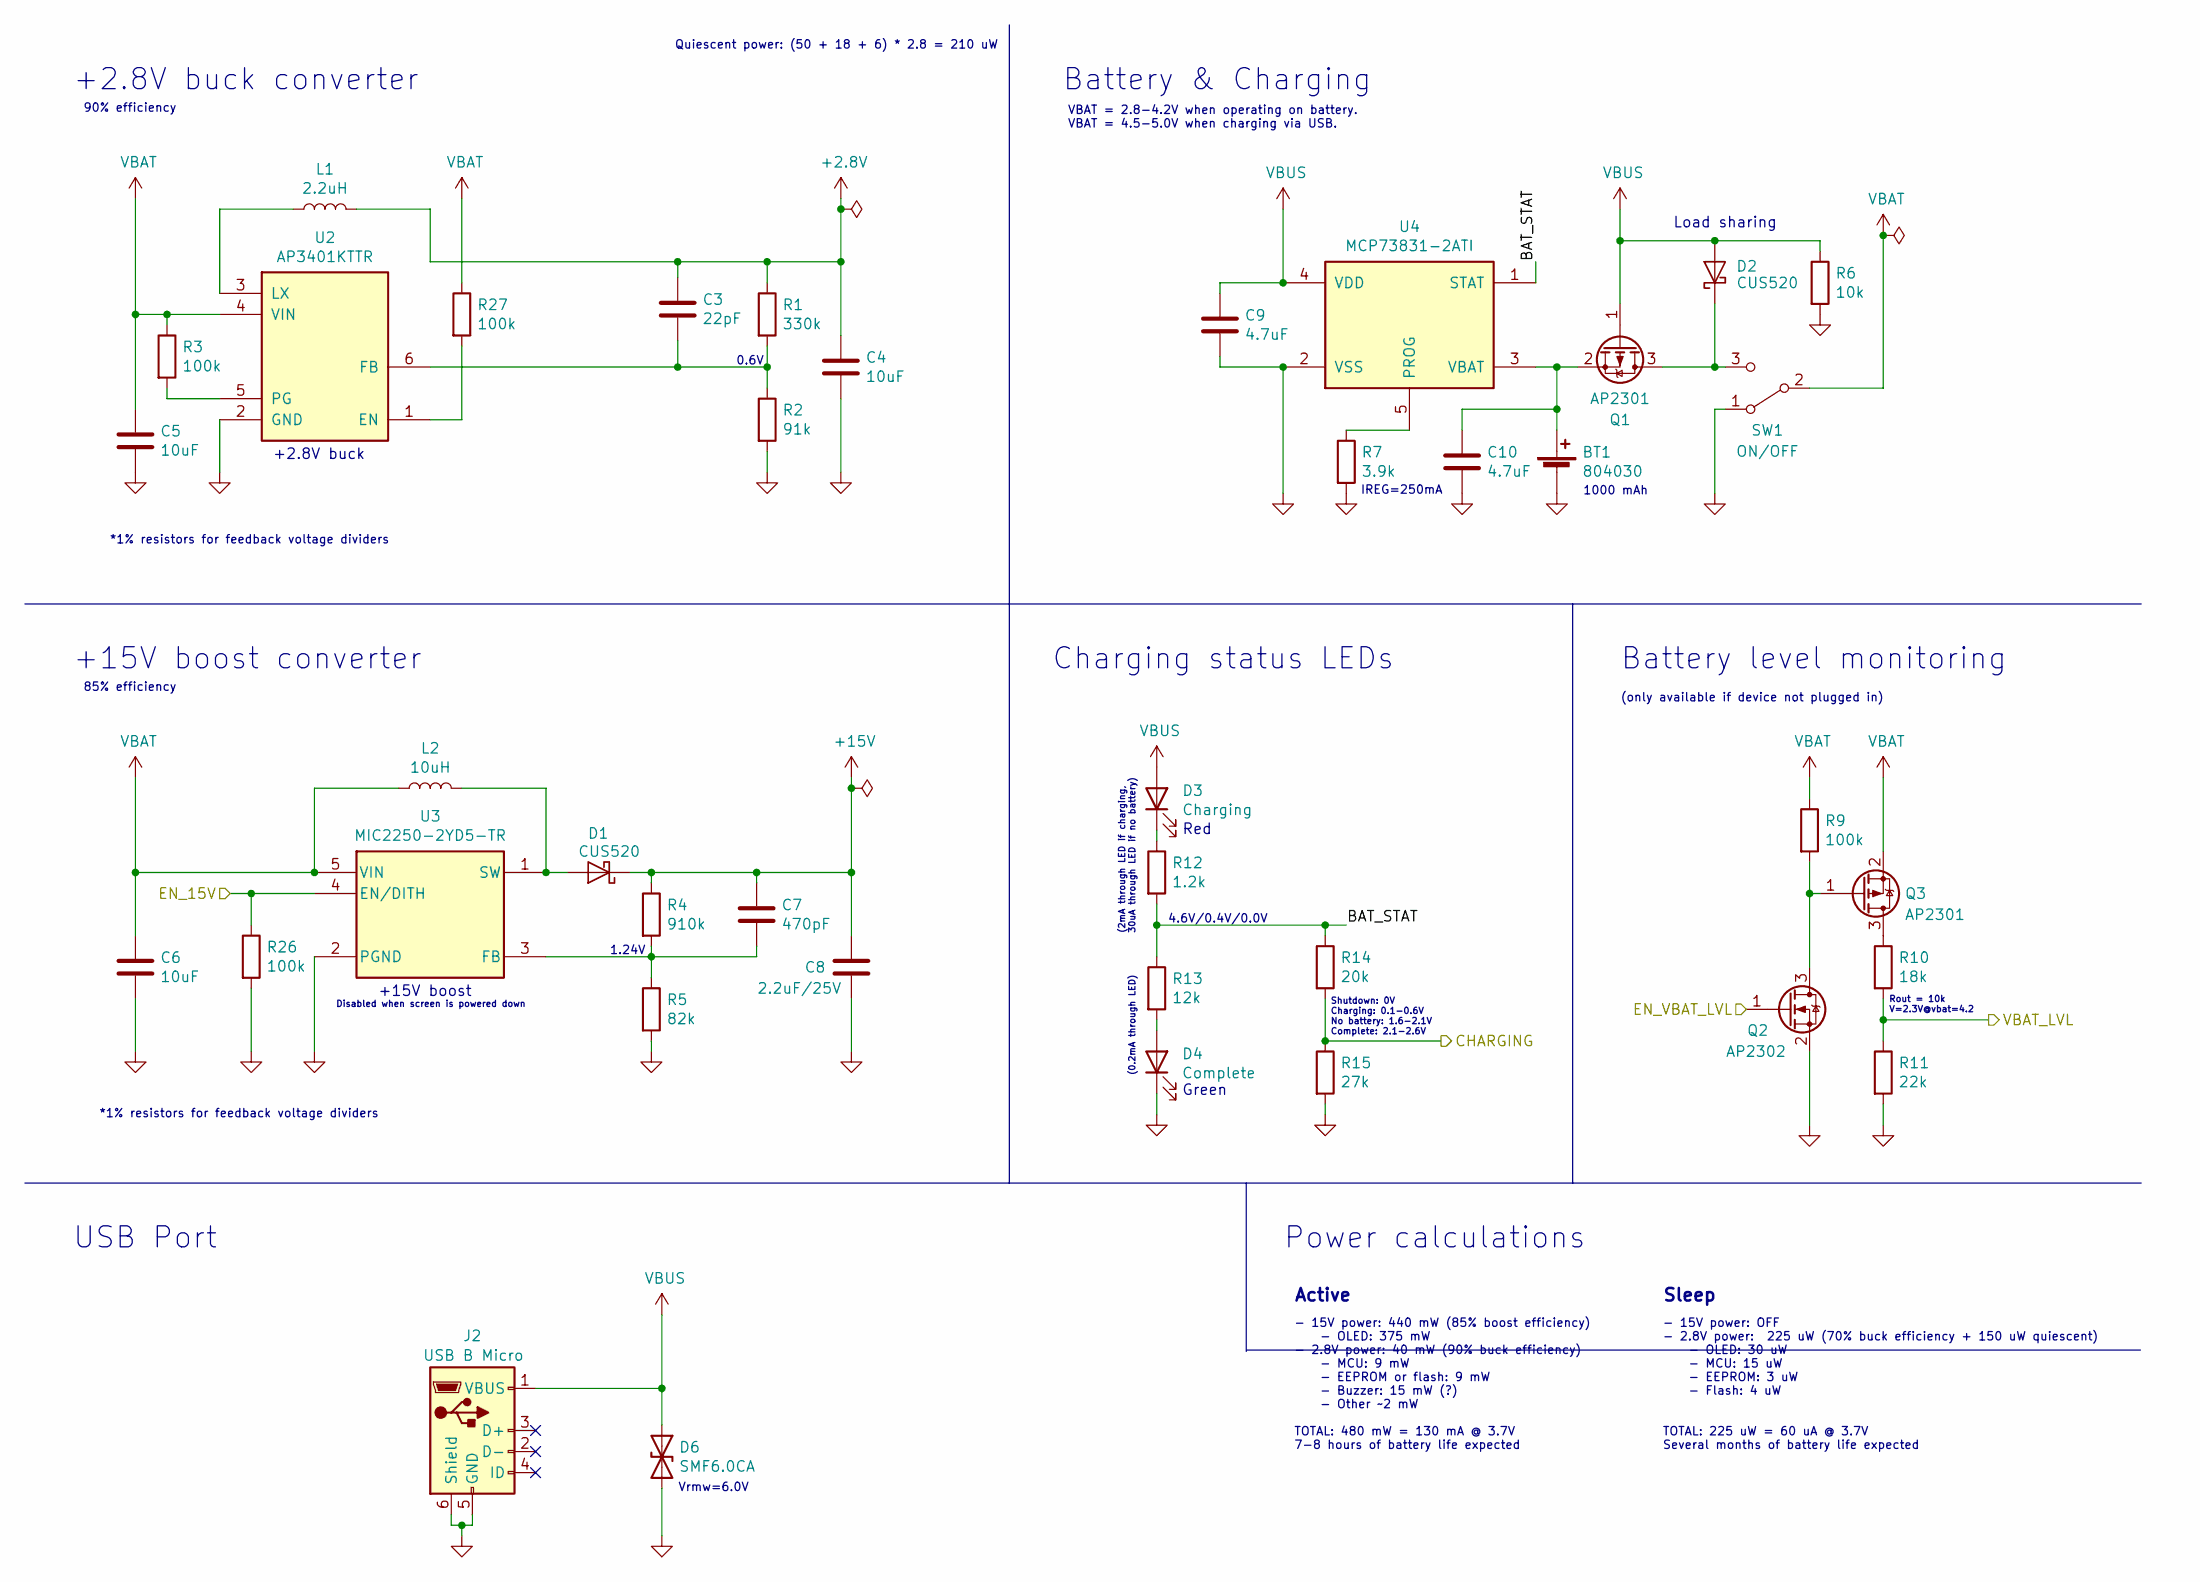
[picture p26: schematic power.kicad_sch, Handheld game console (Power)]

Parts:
BT1: 804030; Battery-804030
C3: 22pF; C_0603_1608Metric
C4, C5, C6: 10uF; C_0805_2012Metric
C7: 470pF; C_0603_1608Metric
C8: 2.2uF/25V; C_0603_1608Metric
C9, C10: 4.7uF; C_0603_1608Metric
D1, D2: CUS520; D_SOD-323_HandSoldering
D3: Charging; D_0805_2012Metric
D4: Complete; D_0805_2012Metric
D6: SMF6.0CA; D_SOD-123F
J2: USB B Micro; CUI_UJ2-MIBH-G-SMT-TR
L1: 2.2uH; L_1210_3225Metric
L2: 10uH; L_1210_3225Metric
Q1, Q3: AP2301; SOT-23
Q2: AP2302; SOT-23
R1: 330k; R_0603_1608Metric
R2: 91k; R_0603_1608Metric
R3, R9, R26, R27: 100k; R_0603_1608Metric
R4: 910k; R_0603_1608Metric
R5: 82k; R_0603_1608Metric
R6: 10k; R_0603_1608Metric
R7: 3.9k; R_0603_1608Metric
R10: 18k; R_0603_1608Metric
R11: 22k; R_0603_1608Metric
R12: 1.2k; R_0603_1608Metric
R13: 12k; R_0603_1608Metric
R14: 20k; R_0603_1608Metric
R15: 27k; R_0603_1608Metric
SW1: ON/OFF; 1825232-1
U2: AP3401KTTR; SOT-23-6
U3: MIC2250-2YD5-TR; SOT-23-5
U4: MCP73831-2ATI; SOT-23-5

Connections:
+2V8: C3.1, C4.1, L1.2, R1.1; also elsewhere on the board
+15V: C7.1, C8.1, D1.1 (C), R4.1; also elsewhere on the board
/CHARGING: R14.2, R15.1; also elsewhere on the board
/EN_15V: R26.1, U3.4 (EN/DITH); also elsewhere on the board
/EN_VBAT_LVL: Q2.1 (G); also elsewhere on the board
/VBAT_LVL: R10.2, R11.1; also elsewhere on the board
/power/BAT_STAT: R12.2, R13.1, R14.1, U4.1 (STAT)
GND: BT1.2 (-), C4.2, C5.2, C6.2, C8.2, C9.2, C10.2, D4.1 (K), D6.2 (A2), J2.5 (GND), J2.6 (Shield), Q2.2 (S), R2.2, R5.2, R6.2, R7.2, R11.2, R15.2, R26.2, SW1.1 (A), U2.2 (GND), U3.2 (PGND), U4.2 (VSS); also elsewhere on the board
unnamed: BT1.1 (+), C10.1, Q1.2 (S), U4.3 (VBAT)
unnamed: C3.2, R1.2, R2.1, U2.6 (FB)
unnamed: C7.2, R4.2, R5.1, U3.3 (FB)
unnamed: D1.2 (A), L2.2, U3.1 (SW)
unnamed: D2.1 (C), Q1.3 (D), SW1.3 (C)
unnamed: D3.1 (K), R12.1
unnamed: D4.2 (A), R13.2
unnamed: L1.1, U2.3 (LX)
unnamed: Q2.3 (D), Q3.1 (G), R9.2
unnamed: Q3.3 (D), R10.1
unnamed: R3.2, U2.5 (PG)
unnamed: R7.1, U4.5 (PROG)
unnamed: R27.2, U2.1 (EN)
VBAT: C5.1, C6.1, L2.1, Q3.2 (S), R3.1, R9.1, R27.1, SW1.2 (B), U2.4 (VIN), U3.5 (VIN); also elsewhere on the board
VBUS: C9.1, D2.2 (A), D3.2 (A), D6.1 (A1), J2.1 (VBUS), Q1.1 (G), R6.1, U4.4 (VDD)

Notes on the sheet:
(only available if device not plugged in)
85% efficiency
Red
Sleep
Power calculations
(0.2mA through LED)
Green
Battery & Charging
- 15V power: OFF - 2.8V power: 225 uW (70% buck efficiency + 150 uW quiescent) - OLED: 30 uW - MCU: 15 uW - EEPROM: 3 uW - Flash: 4 uW TOTAL: 225 uW = 60 uA @ 3.7V Several months of battery life expected
90% efficiency
1000 mAh
0.6V
Vrmw=6.0V
1.24V
*1% resistors for feedback voltage dividers
Battery level monitoring
- 15V power: 440 mW (85% boost efficiency) - OLED: 375 mW - 2.8V power: 40 mW (90% buck efficiency) - MCU: 9 mW - EEPROM or flash: 9 mW - Buzzer: 15 mW (?) - Other ~2 mW TOTAL: 480 mW = 130 mA @ 3.7V 7-8 hours of battery life expected
(2mA through LED if charging, 30uA through LED if no battery)
4.6V/0.4V/0.0V
+2.8V buck converter
VBAT = 2.8-4.2V when operating on battery. VBAT = 4.5-5.0V when charging via USB.
Shutdown: 0V Charging: 0.1-0.6V No battery: 1.6-2.1V Complete: 2.1-2.6V
+15V boost converter
Active
USB Port
Rout = 10k V=2.3V@vbat=4.2
Charging status LEDs
Load sharing
+15V boost
Disabled when screen is powered down
IREG=250mA
+2.8V buck
Quiescent power: (50 + 18 + 6) * 2.8 = 210 uW

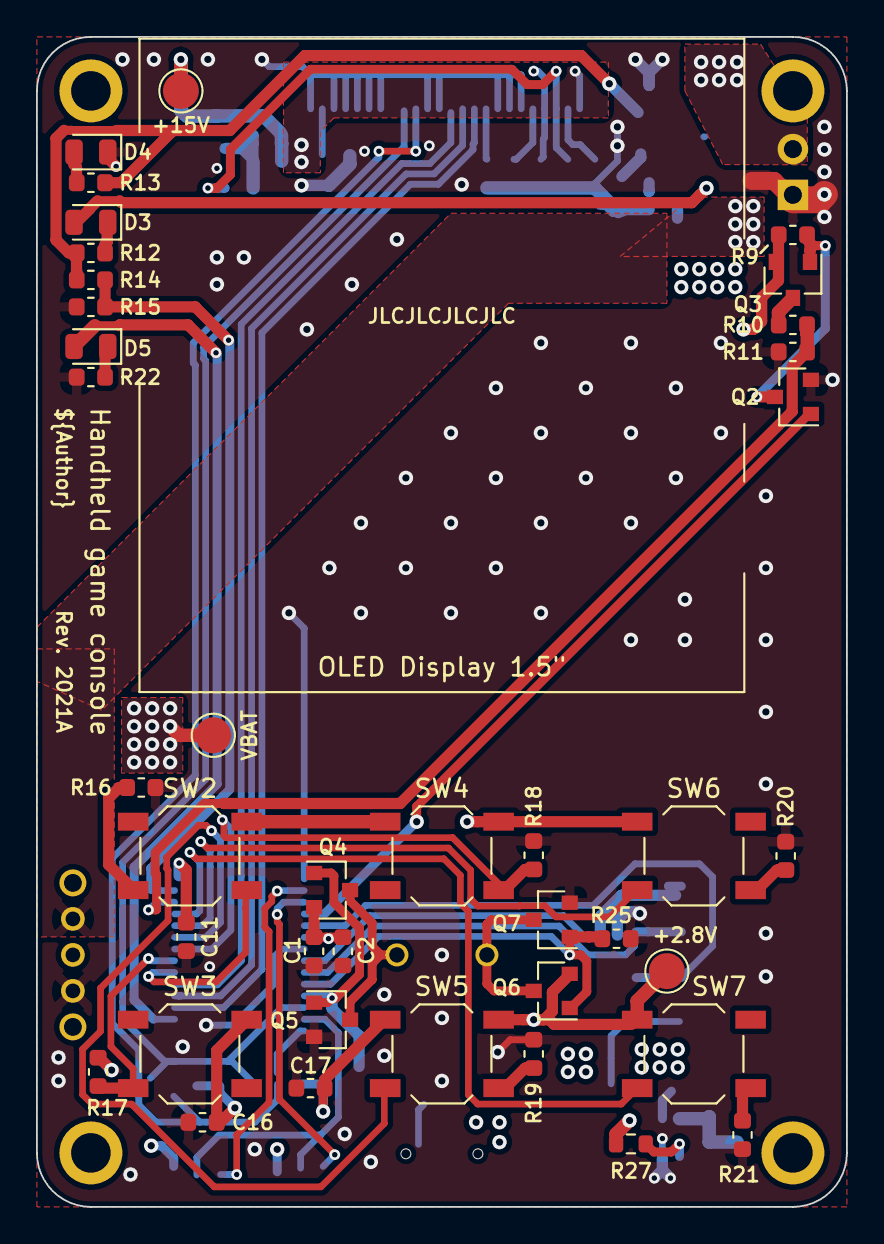
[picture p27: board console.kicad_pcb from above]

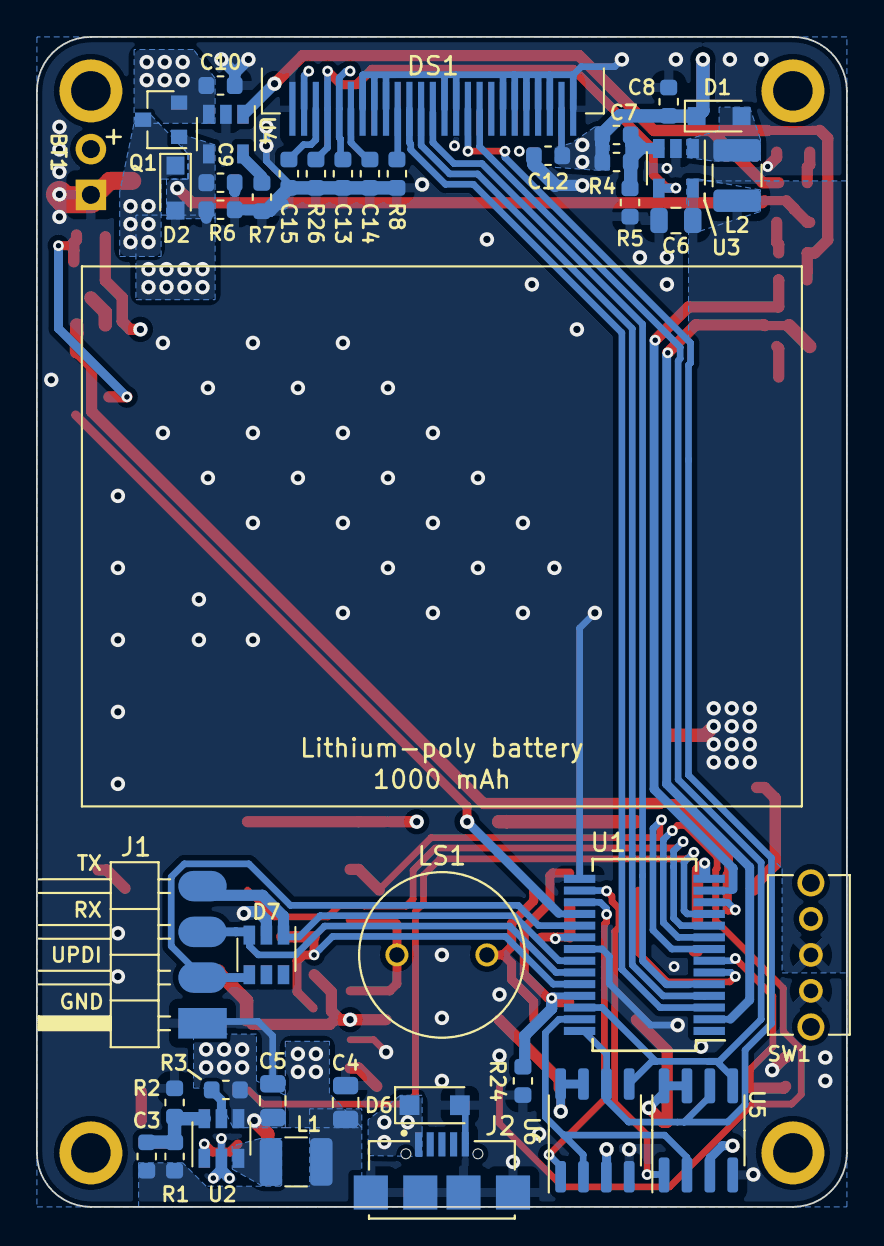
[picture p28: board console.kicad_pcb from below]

Board: 4 copper layers, 45.0 x 65.0 mm, 84 parts (40 on the bottom side), 49 nets.

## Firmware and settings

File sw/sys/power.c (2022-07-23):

/*
 * Copyright 2021 Nicolas Maltais
 *
 * Licensed under the Apache License, Version 2.0 (the "License");
 * you may not use this file except in compliance with the License.
 * You may obtain a copy of the License at
 *
 *     http://www.apache.org/licenses/LICENSE-2.0
 *
 * Unless required by applicable law or agreed to in writing, software
 * distributed under the License is distributed on an "AS IS" BASIS,
 * WITHOUT WARRANTIES OR CONDITIONS OF ANY KIND, either express or implied.
 * See the License for the specific language governing permissions and
 * limitations under the License.
 */

#include <sys/power.h>
#include <sys/defs.h>

#include <util/atomic.h>

#define BATTERY_BUFFER_SIZE 8

#ifdef BOOTLOADER

#include <boot/defs.h>
#include <boot/init.h>
#include <boot/power.h>
#include <boot/display.h>
#include <boot/sound.h>
#include <boot/input.h>

#include <sys/callback.h>
#include <sys/app.h>
#include <sys/display.h>

#include <avr/io.h>
#include <avr/interrupt.h>
#include <avr/sleep.h>
#include "core/led.h"

#define MUXPOS_CHARGE_STATUS ADC_MUXPOS_AIN7_gc
#define MUXPOS_VBAT_LEVEL ADC_MUXPOS_AIN6_gc

#define CALIB_LOAD_COEFF ((const int16_t*) (EEPROM_START + 0))  // 12 B total, Q5.11 coeffs.
#define CALIB_PERCENT_CORRECTION ((const int8_t*) (EEPROM_START + 12))  // 2 B total, int8 coeffs.
#define CALIB_DISCHARGE_CURVE ((const uint16_t*) (EEPROM_START + 14))  // 64 B total, uint16 values.
#define CALIB_DISCHARGE_POINTS 16
#define CALIB_DISCHARGE_POINT_DIST (256 / CALIB_DISCHARGE_POINTS)

// number of seconds between each battery percent updates.
#define BATTERY_PERCENT_UPDATE_PERIOD 10

typedef enum {
    STATE_DONE,
    STATE_STATUS,
    STATE_LEVEL,
} sampler_state_t;

#endif

enum {
    // sleep was scheduled and countdown timer is running.
    STATE_SLEEP_SCHEDULED = 1 << 0,
    // sleep was scheduled and device will be allowed to wakeup from sleep.
    STATE_SLEEP_ALLOW_WAKEUP = 1 << 1,
    // sleep is disabled globally
    STATE_SLEEP_DISABLE = 1 << 2,
    // the battery level monitor is waiting for the average display color value.
    STATE_COLOR_PENDING = 1 << 3,
    // the battery level monitor is ready to update the battery level.
    STATE_UPDATE_BATTERY_LEVEL = 1 << 4,
};

#ifdef BOOTLOADER

// Minimum and maximum ADC readings for each battery status.
// If outside of these intervals, status is unknown.
// VREF = 2.5V
static const uint8_t _BATTERY_STATUS_RANGES[] = {
        130, 210,   // no battery,  bat stat = 1.3 to 2.1 V
        4, 62,      // charging,    bat stat = 0.1 to 0.6 V
        211, 255,   // charged,     bat stat = 2.1 to 2.6 V
        0, 3,       // discharging, bat stat = 0 V
};

static volatile sampler_state_t _sampler_state;  // STATE_DONE at startup
static volatile uint8_t _sleep_countdown;
static uint8_t _battery_percent_buf[BATTERY_BUFFER_SIZE];
// the head is the index in the buffer where the next value will be written.
static uint8_t _battery_percent_buf_head;
static volatile uint8_t _battery_percent_buf_size;
// current averaged battery level, 0-255.
static uint8_t _battery_level;
// battery level update timer counter.
static uint8_t _battery_level_update;

volatile uint8_t sys_power_state;
volatile battery_status_t sys_power_battery_status;  // UNKNOWN at startup
volatile sleep_cause_t sys_power_sleep_cause;
volatile uint16_t sys_power_last_sample;

/** Find the battery status from a voltage measurement and return it. */
static battery_status_t find_battery_status(uint8_t res) {
    // return battery status according to precalculated ranges.
    // if none match, battery status is unknown.
    const uint8_t* ranges = _BATTERY_STATUS_RANGES;
    for (uint8_t status = BATTERY_NONE; status <= (uint8_t) BATTERY_DISCHARGING; ++status) {
        uint8_t min = *ranges++;
        uint8_t max = *ranges++;
        if (res >= min && res <= max) {
            return status;
        }
    }
    return BATTERY_UNKNOWN;
}

static void reset_battery_state(void) {
    _battery_level = 0;
    _battery_percent_buf_size = 0;
    _battery_level_update = 0;
    _sampler_state = STATE_DONE;
}

ISR(ADC0_RESRDY_vect) {
    uint16_t res = ADC0.RES;
    const sampler_state_t state = _sampler_state;
    if (state == STATE_STATUS) {
        battery_status_t status = find_battery_status(res >> 8);
        sys_power_battery_status = status;
        if (status == BATTERY_DISCHARGING) {
            // start conversion for battery level.
            VPORTF.OUT |= PIN6_bm;  // enable switch for reading
            ADC0.MUXPOS = MUXPOS_VBAT_LEVEL;
            ADC0.COMMAND = ADC_STCONV_bm;
            _sampler_state = STATE_LEVEL;
        } else {
            // no battery, or vbat is sourced from vbus,
            // in which case we can't know the battery voltage.
            reset_battery_state();
        }

    } else if (state == STATE_LEVEL) {
        VPORTF.OUT &= ~PIN6_bm;
        sys_power_last_sample = res;
        sys_power_state |= STATE_UPDATE_BATTERY_LEVEL;
        _sampler_state = STATE_DONE;
    }
}

ISR(RTC_PIT_vect) {
    // (called every second)
    RTC.PITINTFLAGS = RTC_PI_bm;

    sys_input_update_inactivity();

    uint8_t countdown = _sleep_countdown;
    uint8_t state = sys_power_state;
    if ((state & STATE_SLEEP_SCHEDULED) && countdown != 0) {
        _sleep_countdown = countdown - 1;
    }

    // indicate that a display color should be computed soon.
    sys_power_state = state | STATE_COLOR_PENDING;
}

void sys_power_start_sampling(void) {
    if (_sampler_state == STATE_DONE) {
        _sampler_state = STATE_STATUS;
        ADC0.MUXPOS = MUXPOS_CHARGE_STATUS;
        ADC0.COMMAND = ADC_STCONV_bm;
    }
}

void sys_power_end_sampling(void) {
    _sampler_state = STATE_DONE;
}

void sys_power_wait_for_sample(void) {
    while (_sampler_state != STATE_DONE);
}

/**
 * Using precalculated coefficients stored in EEPROM, estimate the current
 * load factor (0-255) from the display contrast and color (other factors are ignored).
 * A load factor of 0 is the highest load and 255 is the lowest.
 */
static uint8_t estimate_load(void) {
    uint8_t var[3];
    var[0] = sys_display_get_contrast();
    var[1] = sys_display_get_average_color();
    var[2] = 1;
    int16_t res = 0;
    const int16_t* coeffs = CALIB_LOAD_COEFF;
    for (uint8_t i = 0; i < 3; ++i) {
        for (uint8_t j = 0; j <= i; ++j) {
            int16_t coeff = *coeffs++;
            int24_t term_fix = (int24_t) ((uint16_t) var[i] * var[j]) * coeff;
            res += (int16_t) ((uint24_t) term_fix >> 8);
        }
    }
    if (res < 0) {
        return 255;
    }
    uint16_t ures = (uint16_t) res >> 3;
    if (ures > 255) {
        return 0;
    }
    return 255 - ures;
}
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

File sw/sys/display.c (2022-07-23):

/*
 * Copyright 2021 Nicolas Maltais
 *
 * Licensed under the Apache License, Version 2.0 (the "License");
 * you may not use this file except in compliance with the License.
 * You may obtain a copy of the License at
 *
 *     http://www.apache.org/licenses/LICENSE-2.0
 *
 * Unless required by applicable law or agreed to in writing, software
 * distributed under the License is distributed on an "AS IS" BASIS,
 * WITHOUT WARRANTIES OR CONDITIONS OF ANY KIND, either express or implied.
 * See the License for the specific language governing permissions and
 * limitations under the License.
 */

#include <sys/display.h>
#include <sys/spi.h>
#include <sys/defs.h>

enum {
    STATE_DIMMED = 1 << 0,
    STATE_AVERAGING_COLOR = 1 << 1,
};

#ifdef BOOTLOADER

#include <boot/defs.h>
#include <boot/display.h>
#include <boot/power.h>

#include <avr/io.h>
#include <util/delay.h>

// Fundamental Command Table, p. 33
#define DISPLAY_SET_COLUMN_ADDR       0x15
#define DISPLAY_SET_ROW_ADDR          0x75
#define DISPLAY_SET_CONTRAST          0x81
#define DISPLAY_SET_REMAP             0xa0
#define DISPLAY_SET_START_LINE        0xa1
#define DISPLAY_SET_DISP_OFFSET       0xa2
#define DISPLAY_MODE_NORMAL           0xa4
#define DISPLAY_MODE_ALL_ON           0xa5
#define DISPLAY_MODE_ALL_OFF          0xa6
#define DISPLAY_MODE_INVERTED         0xa7
#define DISPLAY_SET_MUX_RATIO         0xa8
#define DISPLAY_FUNC_SEL_A            0xab
#define DISPLAY_FUNC_SEL_B            0xd5
#define DISPLAY_DISP_OFF              0xae
#define DISPLAY_DISP_ON               0xaf
#define DISPLAY_SET_PHASE_LENGTH      0xb1
#define DISPLAY_SET_CLK               0xb3
#define DISPLAY_SET_GPIO                  0xb5
#define DISPLAY_SET_PRECHARGE_VOLTAGE 0xbc
#define DISPLAY_SET_PRECHARGE_PERIOD  0xb6
#define DISPLAY_SET_GRAYSCALE         0xb8
#define DISPLAY_SET_GRAYSCALE_DEFAULT 0xb9
#define DISPLAY_SET_VCOM              0xbe

// Flags for set remap command, p. 27-29, 33
#define REMAP_COL (1 << 0)
#define REMAP_NIBBLE (1 << 1)
#define REMAP_VERTICAL (1 << 2)
#define REMAP_COM (1 << 4)
#define REMAP_COM_SPLIT (1 << 6)

#define FUNC_SEL_A_INTERNAL_VDD_DISABLE 0x00
#define FUNC_SEL_A_INTERNAL_VDD_ENABLE 0x01

// see core/graphics.c
#define nibble_swap(a) ((a) >> 4 | (a) << 4)
#define nibble_copy(a) ((a) >> 4 | nibble_swap(a))

__attribute__((section(".disp_buf"))) uint8_t sys_display_buffer[];

disp_y_t sys_display_page_height;
disp_y_t sys_display_curr_page_height;

uint8_t sys_display_state;
uint8_t sys_display_contrast;

// used for averaging display color once in a while.
// 24 bits of which 22 are used, lower 4 bits are always 0 and average is located at [21:18].
union {
    uint24_t value;
    uint8_t bytes[3];
} _color_accumulator;

#define color_accumulator_upper (_color_accumulator.bytes[2])
#define color_accumulator_full (_color_accumulator.value)

// Initialization sequence, see datasheet and examples
// OLED display model number is ER-OLED015-3, with a SSD1327 controller.
// Commented out lines correspond to values set at reset and thus not required to be set.
static const uint8_t _INIT_SEQUENCE[] = {
        DISPLAY_DISP_OFF,
        // To appear upstraight, the remap value is 0x53, but the display is upside down (&=~0x10)
        DISPLAY_SET_REMAP, REMAP_COM_SPLIT,
//      DISPLAY_SET_START_LINE, 0x00,
//      DISPLAY_SET_DISP_OFFSET, 0x00,
//      DISPLAY_SET_MUX_RATIO, DISPLAY_NUM_ROWS - 1,
//      DISPLAY_MODE_NORMAL,
        DISPLAY_FUNC_SEL_A, FUNC_SEL_A_INTERNAL_VDD_ENABLE,
        // Values given by manufacturer + attempt to linearize grayscale
        DISPLAY_SET_PHASE_LENGTH, 0x37,
        // DISPLAY_SET_CLK, 0x00,
        DISPLAY_FUNC_SEL_B, 0x02,
        DISPLAY_SET_PRECHARGE_PERIOD, 0x0d,
        DISPLAY_SET_PRECHARGE_VOLTAGE, 0x03,
        DISPLAY_SET_VCOM, 0x07,
//      DISPLAY_SET_CONTRAST, DISPLAY_DEFAULT_CONTRAST,
        DISPLAY_SET_GRAYSCALE, 0, 1, 2, 3, 4, 5, 7, 9, 11, 13, 15, 17, 20, 23, 26, 30,
//      DISPLAY_GPIO, 0x02,
};

static const uint8_t _RESET_CURSOR_SEQUENCE[] = {
        DISPLAY_SET_COLUMN_ADDR, 0x00, DISPLAY_NUM_COLS - 1,
        DISPLAY_SET_ROW_ADDR, 0x00, DISPLAY_NUM_ROWS - 1,
};

ALWAYS_INLINE
static void sys_display_clear_dc(void) {
    VPORTC.OUT &= ~PIN3_bm;
}

ALWAYS_INLINE
static void sys_display_set_dc(void) {
    VPORTC.OUT |= PIN3_bm;
}

static void sys_display_reset(void) {
    VPORTC.OUT |= PIN2_bm;
    for (uint8_t i = 0; i < 2; ++i) {
        _delay_ms(1);
        PORTC.OUTTGL = PIN2_bm;
    }

    // reset state to remove dimmed status as it isn't restored.
    sys_display_state = 0;

    // resetting also resets internal contrast value but we won't set
    // sys_display_contrast here as we'd like to restore it afterwards.
}

static void sys_display_write_data(uint16_t length, const uint8_t data[static length]) {
    sys_spi_select_display();
    sys_spi_transmit(length, data);
    sys_spi_deselect_display();
}

static void sys_display_write_command1(uint8_t byte0) {
    sys_display_clear_dc();
    sys_display_write_data(1, &byte0);
}

static void sys_display_write_command2(uint8_t byte0, uint8_t byte1) {
    uint8_t data[2];
    data[0] = byte0;
    data[1] = byte1;
    sys_display_clear_dc();
    sys_display_write_data(2, data);
}

BOOTLOADER_NOINLINE
static void sys_display_set_contrast_internal(uint8_t contrast) {
    sys_display_write_command2(DISPLAY_SET_CONTRAST, contrast);
}

void sys_display_preinit(void) {
    // to avoid creating a .data section for the bootloader.
    sys_display_contrast = DISPLAY_DEFAULT_CONTRAST;
}

void sys_display_init(void) {
    sys_display_reset();
    sys_display_clear_dc();
    sys_display_write_data(sizeof _INIT_SEQUENCE, _INIT_SEQUENCE);
    // previous contrast was lost on reset, restore it.
    sys_display_set_contrast_internal(sys_display_contrast);
}

void sys_display_sleep(void) {
    // disable VDD regulator
    sys_display_write_command2(DISPLAY_FUNC_SEL_A, FUNC_SEL_A_INTERNAL_VDD_DISABLE);
}

void sys_display_set_enabled(bool enabled) {
    sys_display_write_command1(enabled ? DISPLAY_DISP_ON : DISPLAY_DISP_OFF);
}

void sys_display_set_inverted(bool inverted) {
    sys_display_write_command1(inverted ? DISPLAY_MODE_INVERTED : DISPLAY_MODE_NORMAL);
}

BOOTLOADER_NOINLINE
void sys_display_set_dimmed(bool dimmed) {
    uint8_t contrast = sys_display_contrast;
    if (dimmed) {
        if (sys_display_is_dimmed()) {
            // already dimmed
            return;
        }
        contrast /= 2;
        sys_display_state |= STATE_DIMMED;
    } else {
        if (!sys_display_is_dimmed()) {
            // already not dimmed.
            return;
        }
        sys_display_state &= ~STATE_DIMMED;
    }
    sys_display_set_contrast_internal(contrast);
}

void sys_display_set_gpio(sys_display_gpio_t mode) {
    sys_display_write_command2(DISPLAY_SET_GPIO, mode);
}
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

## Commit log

2021-12-20 Initial commit: hardware
    [console.kicad_pcb, console.sch, power.sch]
2021-12-22 Add missing pull down on buzzer H-bridge, 15V enable
    [console.kicad_pcb, console.sch, power.sch]
2021-12-22 Initial commit: software
    Implemented:
    - UART communication (note RX partially works)
    - Battery status & battery level monitoring
    - LED wrapper
2021-12-22 Move system code to separate folder, power module optimizations
2021-12-22 Automatic battery sampling, battery level buffering, auto shutdown
2021-12-22 Add input (buttons) module
2021-12-23 Implement SPI packet & add EEPROM driver to gcprog
2021-12-24 Add progress & diffing to EEPROM driver
2021-12-24 Add flash driver to gcprog
    Change link baud rate to 500k otherwise reading & writing to flash is painfully slow!
2021-12-27 UART/comms refactor
    - Add debug packets for printing debug info to console, instead of sharing TX with packet system, with debug printing utils
    - Add reset packet
    - Add fast baud rate enable/disable packet
    - Remove confusing bitutils (after all)
    - Increase fast baud rate to 1M
    -
    [init.c, main.c, power.c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]
2021-12-28 Add sound support with 3 channels
    Note: having upload issue, not fully tested.
    [init.c, main.c, sound.c]
2021-12-29 Refactor project structure into libraries + simulator
    -flto currently fails for library, significant size increase due to library functions not being inlined when used within library.
    [eeprom.c, flash.c, init.c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]
2021-12-30 Display driver, graphics draw functions, simulated display
    Note: not tested on hardware yet
2021-12-31 Implement graphics line routines, add font/image prototypes
2021-12-31 Add status LEDs to simulator window
    - Add missing simulation guards on some sim/ headers
    [display.c, main.c, power.c]
2021-12-31 Fix synchronization issue with display buffer
    [display.c]
2022-01-01 Add text & font to graphics module
    - Fix data module in simulator
    - Add file error guards to eeprom/flash_load_file
    [display.c, eeprom.c, flash.c]
2022-01-05 Print display coordinates on click glut
2022-01-06 Add sound simulation
    - Rename GRAPHICS_CHECKS to RUNTIME_CHECKS to also be used in core sound module
    - Fix note not set to none when track ends
    - Fix glyph offset not applied
    - Note: buffer overrun is fairly frequent, might be a bug or a driver issue
    [main.c, power.c, sound.c]
2022-01-07 Sleep scheduling and low battery UI
    - Fix glyph not using correct data when font in program memory.
    - Add sleep packet
    - Power down flash before sleep
    - Add built-in graphics font 3x5
    - Add define to disable comms
    [flash.c, init.c, main.c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]
2022-01-08 Add number dialog item, bug fix
    - Make dialog struct global since there's always only one dialog.
    - Fix input responsiveness issue
    - Reduce wakeup from sleep delay
    [main.c, power.c]
2022-01-08 Remove unused ellipse/circle graphics prototypes
2022-01-08 Dialog improvements & bug fixes
    - Fix up arrow working from action button in dialog with no items
    - Allow custom result codes for built-in dialog actions.
    - Fix bottom of frame not drawn if title + no buttons
2022-01-10 System & core fixes, improvements
    - Add basic random module
    - Fix dialog drawing one extra line between content and buttons
    - Fix graphics_vline corrupting memory (drew past buffer in some circumstances)
    - Fix up button selecting last item in dialog if selection is none.
    - Reduce loop delay (5 ms > systick!)
    - Add constant for all buttons
    - Generate data_flash() constants for arrays
    [main.c]
2022-01-10 Tetris: "how to play" dialog
    - Fix dialog dismiss result not using negative button result if unspecified
2022-01-10 Tetris: render preview pieces & held piece
    - Fix leaderboard dismiss starting game
    - Save options when positive button used
2022-01-10 Add power sleep callbacks
2022-01-14 Fix upload bug & many due firmware fixes
    Note: firmware functions hadn't been tested from this commit to 1874ff4a.
    - firmware:
    - Fix unified data interface not working for eeprom & mcu
    - Add protection against dirty resets
    - Set buzzer output high initially (seems to fix a rare reset glitch)
    - Change display driver to do continuous SPI transfers (supported after all, much faster)
    - Add comms command to sleep
    - Add comms command to set DC & reset pins for display
    - Remove display clear command equivalent to graphics_clear
    - Fix display remap mirrored vs. simulator
    - Fix inverted GPIO enum values in display driver.
    - gcprog:
    - Change default interface t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
    [display.c, flash.c, init.c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]
2022-01-14 Add print screen feature to simulator
2022-01-14 Fix sound corrupting display
    Due to sound track filling its buffer in an interrupt, while SPI transfer for display was in progress.
    [main.c, sound.c]
2022-01-14 Fix various firmware issues
    - Fix display dimmed in interrupt, causing SPI transfer in interrupt (again...)
    - Fix RTC status never 0 on wakeup, infinite loop preventing full wakeup
    - Fix display dimmed flag never set or cleared by display_set_dimmed
    - Fix power sampler state not reset on sleep, could cause infinite loop on wake up waiting for sample.
    [display.c, init.c, main.c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]
2022-01-14 Tetris: blink LED on game over
    - Fix high score dialog shown even if no high score achieved
    [power.c]
2022-01-14 Add signature byte to sound, image & font data
    Limits the impact of reading incorrect data.
    Also fix battery sample buffer not reset on sleep.
    [init.c, power.c, sound.c]
2022-01-15 Tetris: add music & title screen image
    - Preview volume level in options dialog
    - Add different leaderboard state if shown during game or in main menu.
    - Fix blinking LED on game over not stopped if new game started shortly after.
    - Fix outline for hold piece color constantly changing.
    - Fix leaderboard being written past its end if full.
    - Show version info in title screen.
    - Change atomic block implementation for simulator
    - Fix buffer underrun check done even when track has ended
    - Fix invalid sound data warning with sound using less than 3 channels
    - Fix packer regular array type not using maximum element size correctly.
    - Fix data_mcu() macro casting to intptr_t, causing addresses abov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
    [sound.c]
2022-01-15 Add system UI battery status overlay
    - Fix low power sleep cancellable with input activity
    [power.c]
2022-01-16 Tetris: fix input not ignored on wakeup
    input_get_state_immediate worked, but following input_get_state is debounced and delayed, so it indicated the button as released right after.
    [init.c]
2022-01-17 Add -fsanitize to simulator to find bugs
    - Fix buffer underflow in sysui_battery_overlay
    - Remove recursive chain in comms (reduces stack size)
    [main.c]
2022-01-17 Tetris: add dt value to time updates
    Otherwise updates are inconsistent because the current screen takes variable time to render.
2022-01-17 Linearize grayscale levels on display
    Note: will have to check later which settings minimize power consumption.
2022-01-18 Clear display on reset to avoid displaying graphic RAM noise
    [display.c, init.c]
2022-01-18 Power module fixes
    - Speaker causes voltage drop on vbus (?), causing failure to detect no battery condition (becomes unknown), so voltage range was widened a bit.
    - Fix enable battery voltage pin not set as output, which caused intermittent failure to read battery level (surprising it worked at all...)
    - Refactor ADC interrupt code a little, removed useless battery percent cache flag.
    [init.c, power.c]
2022-01-22 Several sound implementation changes, fast comms fix
    - Add two volume levels for channel 2 (to be used for sound effects)
    - Move bits around in out_level register to avoid shift.
    - Fix short pause when changing sound volume (due to disabling TCBs)
    - Remove unused volume increase/decrease functions
    - "Fix" comms failing in fast mode (noinline fixes the bug, an delay only won't do)
    [init.c, main.c, sound.c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]
2022-01-23 Fix channel volume simulator implementation
    [sound.c]
2022-01-29 Add test target for core tests
    Also add support for target-specific tests
    - Remove static in array argument prototype (not supported in C++?)
    - Add "headless" simulator mode that has no GUI and no main function
    - Fix wrong end char in last range of font gen report
    - Fix graphics_rect for 1px wide rect on x=0 or x=127
    make graphics_test TARGET=test TEST=1
    make all_tests TARGET=test TEST=1
    make sample_test TARGET=sample TEST=1
    [display.c, main.c, sound.c]
2022-01-30 Fix cases where display buffer size created short last page
    - Make display_page_yend inclusive
    - Fix implementation issues with different last page height
    - Fix incorrect line spacing runtime check in graphics_set_font
    - Allow changing page height at runtime in simulator
    - Fix headless simulator not initialized in graphics_test
    From here the strategy when making new games is to allocate all leftover RAM to the display buffer, even if it results in weird page heights, like 37, a larger page height will always be faster.
    [display.c, init.c, main.c]
2022-01-30 PCB improvements & enclosure
    - Change revision to 2021B
    - Larger battery connector holes
    - Change buzzer to 8 ohm speaker
    - Add enclosure CAD files
    [console.kicad_pcb, console.sch, enclosure.FCStd]
2022-01-31 Change indexing for raw images: implicit index
    - Raw image layout is predictable hence index is useless. Seeking to the first row is possible trivially, provided that the encoder state is reset on each row.
    - Few swap optimizations (a color always has high nibble = 0).
    [display.c]
2022-02-05 Add linker script to optimize RAM usage
    - Add section to share RAM with display buffer, for temporary data (wouldn't have been a problem with a heap!).
    - Add script to better calculate section size (other methods have some shortcomings)
    - Put some static variables in noinit section (not much of an optimization, more self documentation actually)
    - Fix display state not reset on display reset.
    [display.c, power.c, sound.c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]
2022-02-05 Migrate to KiCad 6
    [console.kicad_pcb, console.kicad_sch, console.sch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]
2022-02-06 Bug fix, shared buffer memory, graphics performance improvement
    - Use shared memory for save buffer in tetris
    - Use unused GPIOR1 to GPIOR3 for slightly improving graphics performance (had to rename EEPROM_SIZE due to including avr/io.h in display.h)
    - Fix dialog & battery image data (bad flag byte after last changes)
    - Add defines to remove unused graphics features in tetris
    [display.c, eeprom.c, flash.c]
2022-02-26 Tetris: bug fixes & improvements
    - Increase block constrast (some blocks were really hard too see on gc), and update title screen image accordingly
    - Add access to general options from pause dialog.
    core/sys bugs:
    - Fix sound_start and sound_stop not stoppping or
    starting notes on affected channels.
    - Fix buffer underflow in dialog text field if all blank.
    tetris bugs:
    - Fix high score music playing even when music disabled
    - Fix drop delay not reset correctly on new game
    - Fix options not being saved when opening "more options" dialog
    [init.c, sound.c]
2022-04-24 Tetris: several improvements
    - Pause between game over and dialog showing up
    - Always use normal tempo in in-game menus
    - Fix lock delay not updated if move fails and piece is at bottom
    - Move "preview pieces" settings to extra options dialog
    - Clear sound effect queue on game over.
    [sound.c]
2022-04-24 PCB: removed reset monitor
    Causes drop in power when USB is disconnected and not really necessary.
    [console.kicad_pcb, console.kicad_sch, power.kicad_sch]
2022-05-22 Bootloader
    Refactor whole project, splitting functions into bootloader and app.
    The bootloader has a start screen with the list of installed apps, and it loads
    apps by copying their code from flash to internal memory.
    The bootloader has control of the execution, invoking the app through callbacks.
    It also takes care of showing the low battery screen.
    There are also several symbols in the bootloader that the app can link to.
    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
    [target.cfg]
2022-05-23 System app
    - Add defines in dialog to disable features to lower code size.
    - Add define to use EEPROM in absolute mode (for bootloader and system app)
    - Fix include leaking system API in several places
    - Fix boot version not read correctly due to make lazy initialization
    - Remove all pthread uses, wasn't really needed.
    [target.cfg]
2022-05-23 Add exit button to Tetris app
2022-05-28 SPI device emulation and various fixes
    - Flash and EEPROM are not entirely in the core library, same code runs in simulation.
    - Add --sim mode to gcprog as a UART client to the simulator
    - Abstraction over external memory simulation functions.
    - Fix wrong load address for shared data section
    - Fix unable to read whole memory in raw access mode in gcprog
    - Fix broken test target with previous changes to Makefiles
    [target.cfg]
2022-05-28 Fix atomic EEPROM write, other fixes
    - Fix SPI deselect not called on init in simulator.
    - Fix emulated SPI memory not masking addresses to size.
    [eeprom.c, flash.c, init.c]
2022-05-28 Update graphics image tests (remove horizontal region)
    - Fix image encoder not checking max dimensions
    - Add runtime check for image x bounds.
    - Fix color byte not reset on row boundary when encoding 1-bit raw images
    - Auto fix path when running standalone encode utilities.
2022-05-28 PCB: removed power monitor
    Far from enough capacity on board to ever be useful.
    Power monitor was envisioned to prevent EEPROM corruption. This was instead prevented with atomic operation (copy before write).
    [console.kicad_pcb, console.kicad_sch, power.kicad_sch]
2022-06-03 Several fixes: bootloader now working on hardware
    Bootloader:
    - Select last loaded app by default.
    - Prevent signature of some BOOTLOADER_NOINLINE functions changing due to constant propagation.
    - Remove lock on oscillator calibration registers preventing clock calibration, see errata.
    - Program fuses with the HEX file instead of manually.
    - Fix wrong protected write type used for enabling SPM.
    - Fix multiple missing (NOLOAD) in linker script that causes sections to appear in HEX file.
    - Fix power callbacks being call when in bootloader, when they aren't defined.
    - Fix wrong flash page size 256B -> 128B.
    - Fix IVSEL bit not set to put interrupt vector table in boot section.
    - Fix bootloader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
    [target.cfg]
2022-06-03 Change systime_t type to 16 bits
    Always taken as difference of two times, no use in being too big.
    [target.cfg]
2022-06-04 Fix last input issues, last input now included in system
    - Fix last input not ignored when loading app, causing immediate click on startup.
    - Fix last selection not also setting first shown attribute in bootloader.
    [target.cfg]
2022-06-04 System app fixes
    - Fix battery voltage shown when not discharging.
    - Fix relative flash read used to read app name and author.
2022-06-05 Several fixes
    - Fix sys_eeprom_read_absolute not working from addresses >=256 due to unwanted interprocedural optimization (added externally_visible attribute).
    - Fix EEPROM erase not working from gcprog.
    - Fix system app not using actual index in flash when reading name and author.
    - Fix eeprom_buf being output to boot symbols (not necessarily at same location).
    - Add --details option to gcprog list command.
    - Tetris: remove unused includes from sys.
    [target.cfg]
2022-06-12 Improve battery level estimation, bug fixes
    - Add command to calibrate battery in gcprog and system app.
    - Add script to analyze measured data and generate coefficients for the power module.
    - Add option to disable sleep.
    - Power: use coefficients to estimate load in order to better estimate battery level.
    - Remove special H-bridge sound level: it worked, but wasn't much louder despite 2-3x current usage.
    - Remove unused expected packet type in gcprog.
    - Increase bootloader size to 8448 B.
    - Set channel2 volume manually to completely remove the data section from the bootloader.
    - Changed several bool variables by flags to reduce code size.
    - Fix wrong SYSTICK_MAX value in simulator.
    - Fix TC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
    [target.cfg]
2022-06-12 Fix concurrency issue with simulated flash and eeprom.
    [eeprom.c, flash.c]
2022-06-12 Add -mcall-prologues to compile app, link with extra symbols in boot
    - Utility to better filter boot symbols, to include: mul, div, call-prologues stuff.
    - Callback vectors table had to be created in assembly because -mcall-prologues didn't work with current impl.
    - Fix UART callback generating a "ret" instruction instead of "reti" when unused.
    - The setup callback is now mandatory to implement.
    [target.cfg]
2022-06-16 TWorld: basic UI
    [target.cfg]
2022-06-17 TWorld: level pack selection
    - Asset packer fixes:
    - Fix missing array when last packed object belongs in an array.
    - Fix missing array when consecutive objects form different arrays.
    - Fix underscore not allowed in group name.
    [target.cfg]
2022-06-23 Minor bootloader fixes
    - Include utils/uint8_t_to_str in bootloader API.
    - Fix runtime checks never enabled in dialog module.
    - Fix battery percent indicating 0 on battery status change (update counter not reset), and likely on sleep wakeup also.
    - Fix wrong progress bar size in system app memory dialog.
    [target.cfg]
2022-06-23 TWorld: fixes after first hardware test
    - Fix wrong frame delay comparison causing low FPS.
    - Fix missing cast in LZSS 2 bytes backref decoding.
    - Fix level pack rendering showing one extra pack when less than 4 packs.
    Core library:
    - Fix annoying clang-tidy warning asking to use lround in millis_to_ticks.
    - Add FPS monitor utility.
    At this point a 1 actor grid results in max 16.2 FPS, there is still optimization to do!
2022-06-24 TWorld: show time left with inventory, low time counter
    - Track time left instead of current time.
    - Hide inventory when pause dialog is shown.
    - Fix unlocked packs cleared by saving options.
2022-07-01 TWorld: level tests, level pack unlocking
    - Add automatic level tests for all levels in all packs.
    - Unlock level packs if previous has a certain completion ratio.
    - Fix cloner copying actor index of parent to clone.
    - Fix misplaced return in teleport_actor.
    - Fix wrong THIN_WALL_DIR_TO mask.
    - Fix blob PRNG used for tests.
    Misc fixes:
    - Fix dependencies .d files for C++ source
    - Remove -fpack-struct which is useless on AVR, can't be used with Googletest, and thus causes issues when mixed. Packing is done on a per struct basis instead (PACK_STRUCT).
    [target.cfg]
2022-07-02 Bootloader & core library fixes
    - Fix CRC check failing when code size is multiple of page size.
    - Fix boot symbols filter not excluding some unwanted symbols.
    - Misc fixes to remove warnings on avr-gcc 12 (but avr-gcc 12 not working yet...)
    - Fix sleep countdown not working in simulator.
    [target.cfg]
2022-07-02 TWorld: add section to help dialog to show tile types
    - Fix level pos not updated when "next level" button is used.
2022-07-03 TWorld: swimming, burned & drowned chip tiles
    - Fix wrong state delay on fail/complete.
    [target.cfg]
2022-07-10 TWorld: add sound effects
    [target.cfg]
2022-07-10 TWorld: music & tile improvements
    - More recognizable recessed wall & trap.
    - Fix missing notes in music vs MIDI playback.
    [target.cfg]
2022-07-23 Battery percent round up, restore contrast after sleep
    - Fix battery percent not rounded up (100% not reacheable, long time at 0%).
    - Fix contrast setting not restored correctly after wakeup from sleep (set to default).
    [target.cfg]
2022-07-23 TWorld: minor bug fixes
    - Fix actor not appearing on top of chip after death if dying straight out of cloner.
    - Fix end music only played when first dying.
    [target.cfg]
2022-07-29 TWorld: change green key color slightly
    Easier to differentiate from yellow key.
    [target.cfg]
2022-08-28 TWorld: fix chip sound not played after last chip picked up
    [target.cfg]
2022-09-11 TWorld: remove black (0) from most tiles
    Note: it doesn't seem to help at all, but whatever. In theory black (0) involves no 1st precharge on the OLED so it might have cause issues for pixels further on the scanline but turns out it isn't the case.
    - Made ice texture slightly lighter
    - Update menu and cover images
2022-10-08 TWorld: teleporter performance improvements
    Cache teleporter positions to avoid scanning
    the whole map each time an actor teleports.
    This was especially problematic in CCLP2/68,
    where after triggering a trap the gameplay went
    to about 4 FPS. With this change, it's around 8.
    For levels with >128 teleporters, the old method
    is still used. For levels with no teleporters,
    the old method is used to avoid scanning the whole
    map for no reason.
    [target.cfg]

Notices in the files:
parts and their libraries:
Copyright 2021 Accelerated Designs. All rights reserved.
